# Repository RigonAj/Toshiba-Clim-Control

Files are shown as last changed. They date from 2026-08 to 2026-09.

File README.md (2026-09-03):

# Pilotage infrarouge de climatiseurs Toshiba par ESP32

Deux climatiseurs Toshiba, **aucune fonction connectée**, une seule télécommande. Ce projet leur en
donne une : deux boîtiers autonomes à base d'ESP32-S3 qui rejouent le protocole infrarouge de la
télécommande d'origine, servent leur propre interface Web et tiennent un planning horaire.

**Sans serveur domotique, sans cloud, sans machine allumée en permanence** — chaque boîtier fonctionne
seul, y compris si l'autre est débranché.

<p align="center">
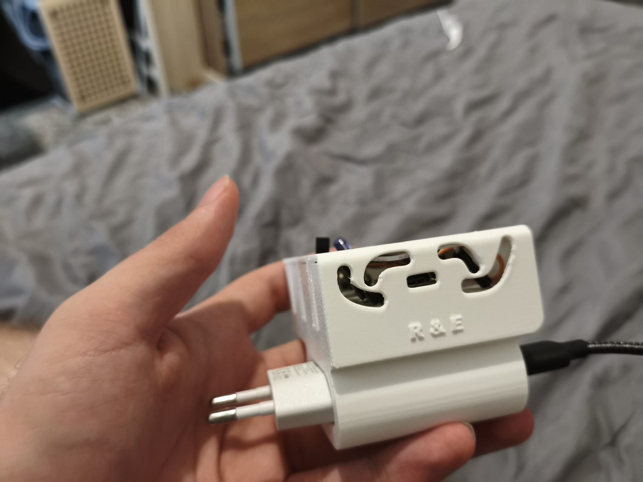
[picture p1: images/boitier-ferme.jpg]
Le boîtier fermé, monté sur son chargeur USB
  
</p>

## Ce que ça fait

- **Rétro-ingénierie du protocole** de la télécommande Toshiba WH-TG01NE, mesuré au récepteur IR
  plutôt que supposé.
- **Émission infrarouge** par un étage transistor + LED IR modulé à 38 kHz.
- **Interface Web servie par la carte elle-même**, en fichiers statiques : la modifier est un
  téléversement, pas une recompilation.
- **Planning horaire** en escalier, avec des points « maintenus » qui neutralisent un rallumage à la
  télécommande.
- **Boîtier conçu et imprimé en 3D**, qui se clipse sur un chargeur USB mural.

## Le résultat principal — le protocole est mesuré

C'est le verrou du projet, et il est levé. La télécommande émet un `TOSHIBA_AC` standard de **72 bits**
(modèle *Remote A*), répété deux fois par appui, porteuse 38 kHz.

```text
octet    0    1    2    3    4    5    6    7    8
        F2   0D   03   FC   01   4 0  00   00   41
                                 │              └── checksum = XOR des 8 premiers octets
                                 └── quartet haut = température − 17
```

Le checksum et l'encodage de la température sont **vérifiés sur tous les états capturés**. Les champs
mode, ventilation et swing restent à identifier : ils demandent la campagne de captures complète.

Preuve de bout en bout : la carte émet une trame que **son propre récepteur redécode octet pour
octet**, douze fois sur douze.

## Où ça en est

| | |
|---|---|
| Protocole de la télécommande | ✅ identifié et vérifié |
| Étage d'émission IR | ✅ monté et validé (boucle locale 12/12) |
| Interface Web | ✅ servie par la carte, testable sans matériel |
| Campagne de captures (mode / ventilation / swing) | 🟡 en cours |
| Preuve sur le climatiseur réel | 🟡 débloquée — exige d'être devant l'unité intérieure |
| Firmware définitif ESP-IDF | ⬜ volontairement pas écrit : le codec serait bâti sur des suppositions |

## Le matériel

| Élément | Choix |
|---|---|
| Carte | **Seeed XIAO ESP32-S3** (8 Mo flash, 8 Mo PSRAM, antenne IPEX) |
| Réception IR | TSOP38238, alimenté depuis un GPIO — 1,5 mA sur 40 mA admissibles |
| Émission IR | LED IR + transistor commuté à 38 kHz |
| Alimentation | chargeur USB mural, sur lequel le boîtier se clipse |

Le boîtier a été **relevé à la main sur une photo du chargeur**, puis dessiné par-dessus — il n'existait
pas de modèle de cette pièce.

| Relevé CAO sur photo | Prototype sur plaque d'essai | Carte perforée |
|---|---|---|
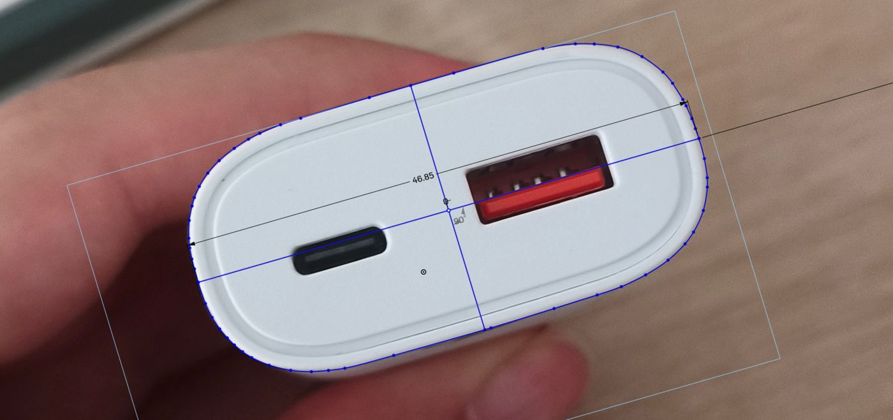
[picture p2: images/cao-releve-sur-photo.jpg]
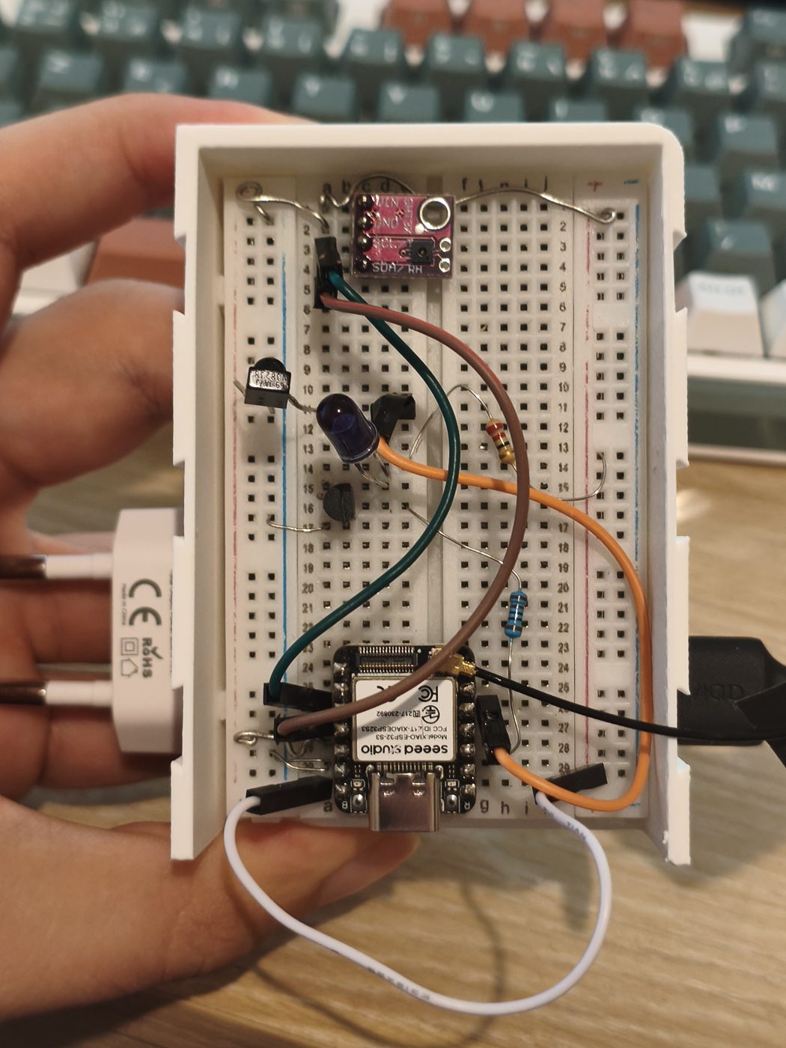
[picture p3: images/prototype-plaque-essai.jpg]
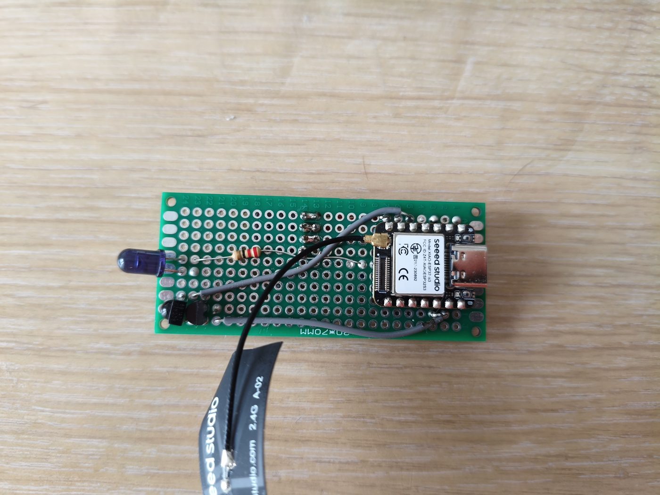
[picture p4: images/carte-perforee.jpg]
|  |  |  |

| Monté sur le chargeur | En place |
|---|---|
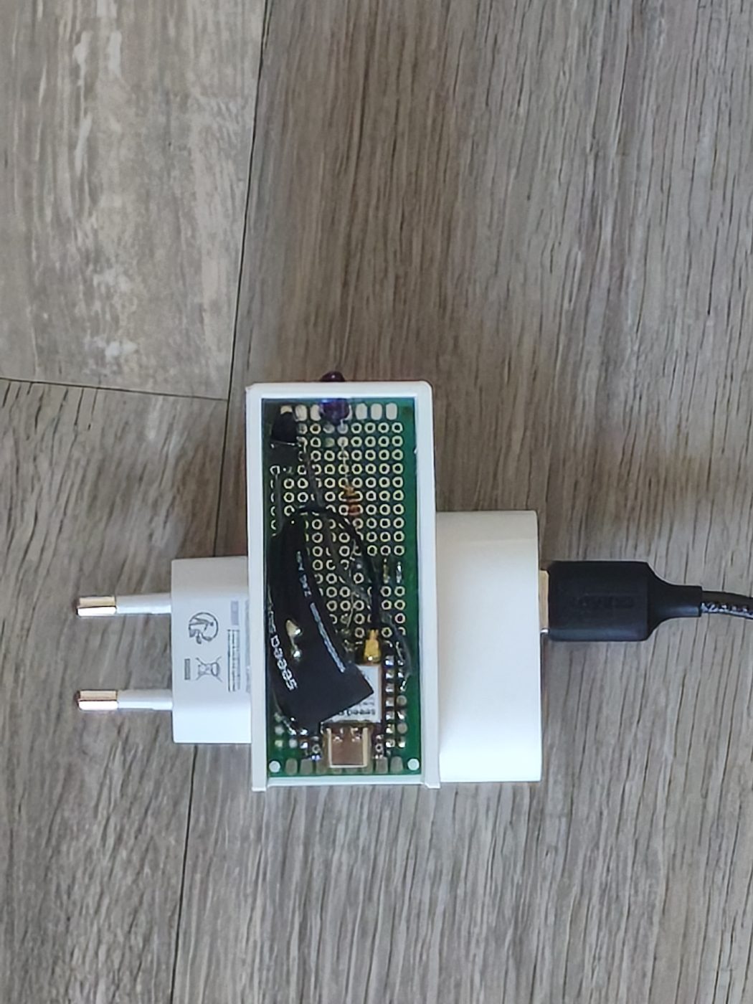
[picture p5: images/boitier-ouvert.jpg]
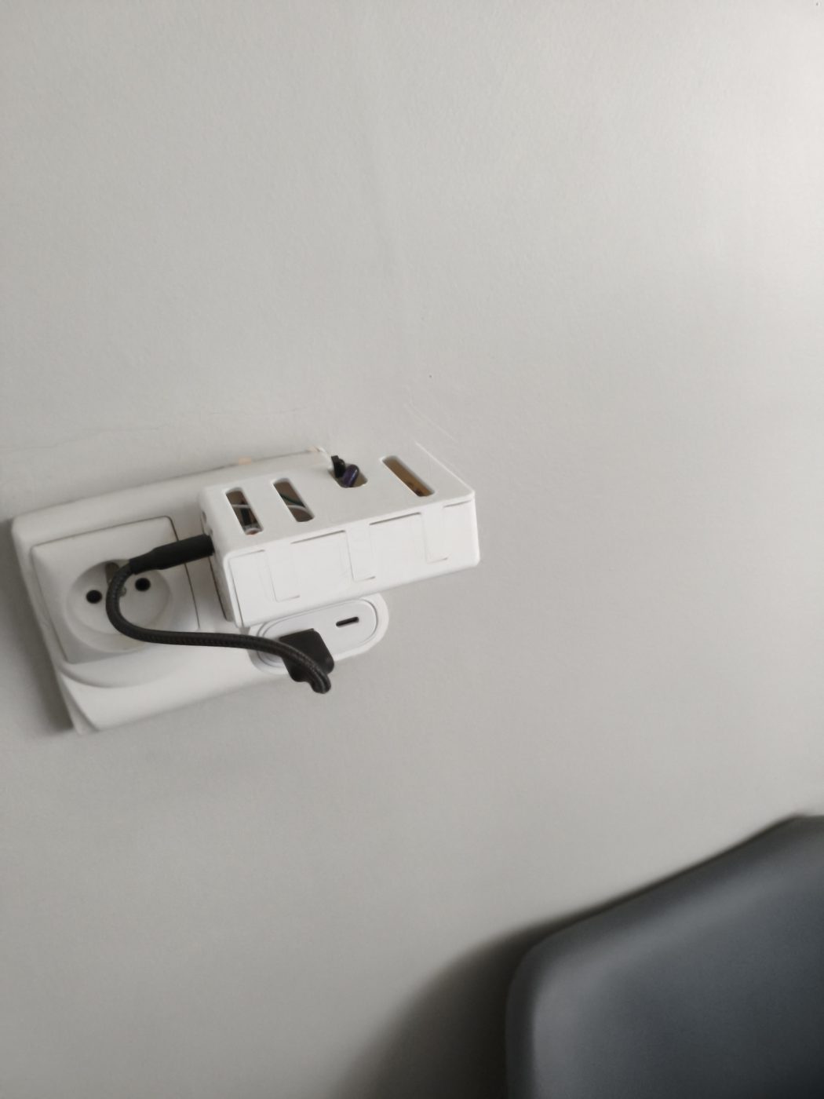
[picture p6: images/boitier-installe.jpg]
|  |  |

Le modèle du boîtier est fourni : [`cad/boitier-clim.step`](cad/boitier-clim.step).

## Contenu du dépôt

```text
ir-capture/                  firmwares de mise au point (PlatformIO) — capture, diagnostic, émission, interface
toshiba-climate-controller/  firmware définitif (à venir) et l'interface Web, en fichiers statiques
captures/                    relevés de la télécommande — des mesures physiques, le contenu le plus précieux
tools/                       export des captures en JSON, et une maquette d'API pour travailler sans matériel
cad/, images/                boîtier imprimé en 3D
docs/                        conception, journal de tests, carnet de mise au point
```

## Essayer sans matériel

L'interface ne dépend ni du codec, ni de la carte. Deux boîtiers simulés, un par terminal :

```bash
python tools/mock_api.py --port 8081 --name Salon --peer "Chambre=http://127.0.0.1:8082"
```

```bash
python tools/mock_api.py --port 8082 --name Chambre --peer "Salon=http://127.0.0.1:8081"
```

Puis ouvrir `http://127.0.0.1:8081/`. Les fichiers de `web/` sont servis tels quels : recharger la page
suffit après modification.

## Avec la carte

```bash
cp ir-capture/include/secrets.example.h ir-capture/include/secrets.h
```

Y mettre le SSID et le mot de passe — **le Wi-Fi doit être en 2,4 GHz**, l'ESP32-S3 ne voit pas le
5 GHz, et l'antenne IPEX doit être branchée avant la mise sous tension. Puis, depuis `ir-capture/` :

```bash
pio run -e webui --target uploadfs && pio run -e webui --target upload && pio device monitor
```

L'adresse IP s'affiche sur la console. Les autres environnements (`capture`, `scan`, `autodetect`,
`txtest`, `carrier`, `loopback`) sont décrits dans le carnet de mise au point.

## Documentation

| Document | Contenu |
|---|---|
| [docs/plan-projet-clim-toshiba-esp32.md](docs/plan-projet-clim-toshiba-esp32.md) | dossier de conception — la référence |
| [docs/cahier-des-charges-v2.md](docs/cahier-des-charges-v2.md) | périmètre étendu : planification et interface |
| [docs/api-v2.md](docs/api-v2.md) | contrat entre l'interface et le firmware |
| [docs/journal-de-tests.md](docs/journal-de-tests.md) | relevés datés, diagnostics, pannes et leur résolution |
| [docs/carnet-mise-au-point.md](docs/carnet-mise-au-point.md) | environnement, outils, câblage, commandes |
| [docs/migration-nouveau-pc.md](docs/migration-nouveau-pc.md) | reprendre le projet sur une autre machine |

## Limites assumées

- Le firmware `webui` n'est **pas** le firmware définitif : ni mot de passe, ni OTA, ni configuration
  persistante. Il ne s'utilise que sur le réseau domestique.
- L'étage d'émission est monté avec des valeurs de substitution : portée d'environ **1,5 m** au lieu
  de 1 à 5 m. Suffisant pour la preuve, pas pour l'installation définitive.
- L'infrarouge ne permet pas d'**empêcher** un démarrage : un point « maintenu » laisse la clim
  s'allumer, puis l'éteint. L'interface l'annonce plutôt que de le masquer.
- Aucune capacité n'est affichée comme acquise tant qu'elle n'est pas mesurée : les champs non
  vérifiés portent une pastille **non vérifié** dans l'interface.

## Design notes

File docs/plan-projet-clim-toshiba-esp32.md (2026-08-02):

---
title: "Projet complet — Pilotage de deux climatiseurs Toshiba par ESP32 et infrarouge"
author: "Dossier de conception"
date: "1er août 2026"
version: "1.1"
lang: "fr"
---

# Projet complet — Pilotage de deux climatiseurs Toshiba par ESP32 et infrarouge

> **Version 1.1 — 1er août 2026**  
> Cible initiale : climatiseur Toshiba `RAS-B18B2KVG-E`, télécommande `WH-TG01NE` portant aussi l'inscription `40525B`.  
> Carte retenue : **Seeed Studio XIAO ESP32-S3**.

### Changements de la version 1.1

La carte cible passe d'un ESP32 DevKit V1 à un **XIAO ESP32-S3** (ESP32-S3R8, 8 Mo de flash, 8 Mo de PSRAM). Ce n'est pas un simple changement de format : le SoC, le brochage disponible, la taille de flash, le périphérique RMT et la liaison série changent tous.

| Point corrigé | Version 1.0 | Version 1.1 |
|---|---|---|
| Brochage IR | GPIO26 / GPIO27 / GPIO25 | D1 (GPIO2) / D2 (GPIO3) / bouton BOOT (GPIO0) |
| Raison | — | Sur ESP32-S3, les GPIO26 à 37 sont réservés à la flash SPI et à la PSRAM octale |
| Flash | 4 Mo, binaire limité à 1,5 Mo | 8 Mo, partitions OTA de 3 Mo, contrainte levée |
| RMT | Blocs de 64 symboles | Blocs de **48** symboles, DMA disponible sur S3 |
| Filtre RX | « ignorer les impulsions < 100 µs » | Impossible au niveau matériel (plafond ~3 µs), filtrage logiciel |
| Console | UART 115200 bauds | USB-Serial-JTAG natif, débit sans objet |
| Étage LED IR | 39 Ω, ≈ 90 mA crête | 22 Ω, ≈ 155 mA crête, pour la portée visée |
| Base du transistor | 330 Ω | 1 kΩ (saturation moins violente) |
| Alternatives | 3 étudiées | Ajout de l'option ESPHome (§17.4) |
| Phase de capture | Firmware de diagnostic à écrire | Chemin rapide `IRremoteESP8266` d'abord (§8.0) |

## Sommaire

1. [Résumé exécutif](#1-résumé-exécutif)
2. [Ce qui est confirmé et ce qui reste à mesurer](#2-ce-qui-est-confirmé-et-ce-qui-reste-à-mesurer)
3. [Objectifs, périmètre et critères de réussite](#3-objectifs-périmètre-et-critères-de-réussite)
4. [Architecture générale](#4-architecture-générale)
5. [Matériel et nomenclature](#5-matériel-et-nomenclature)
6. [Schéma de câblage](#6-schéma-de-câblage)
7. [Architecture du firmware ESP-IDF](#7-architecture-du-firmware-esp-idf)
8. [Identification et validation du protocole IR](#8-identification-et-validation-du-protocole-ir)
9. [Modèle d'état et comportement](#9-modèle-détat-et-comportement)
10. [Interface Web et API](#10-interface-web-et-api)
11. [Réseau, accès WireGuard et sécurité](#11-réseau-accès-wireguard-et-sécurité)
12. [Mises à jour OTA et récupération](#12-mises-à-jour-ota-et-récupération)
13. [Déroulement du projet](#13-déroulement-du-projet)
14. [Plan de tests et recette](#14-plan-de-tests-et-recette)
15. [Risques et mesures de réduction](#15-risques-et-mesures-de-réduction)
16. [Installation, exploitation et maintenance](#16-installation-exploitation-et-maintenance)
17. [Alternatives étudiées](#17-alternatives-étudiées)
18. [Références](#18-références)

---

## 1. Résumé exécutif

Le projet consiste à construire **deux boîtiers autonomes**, un par climatiseur. Chaque boîtier comprend :

- une carte Seeed Studio XIAO ESP32-S3 ;
- un émetteur infrarouge suffisamment puissant pour commander la clim ;
- un récepteur infrarouge 38 kHz qui écoute aussi la télécommande d'origine ;
- une interface Web locale embarquée ;
- un firmware natif ESP-IDF, sans dépendance à un service cloud.

Le premier boîtier, `clim-salon`, servira de **tableau de bord principal**. Il affichera les deux climatiseurs et transmettra les commandes destinées au second boîtier, `clim-chambre`, sur le réseau local. Chaque boîtier restera néanmoins utilisable directement si l'autre est indisponible.

L'accès depuis l'extérieur de la maison passera exclusivement par le serveur **WireGuard déjà actif sur le routeur Asus**. Aucun ESP32 ne sera exposé directement sur Internet et aucune redirection de port ne devra être créée.

Le projet est techniquement faisable, mais il possède un jalon incontournable : **capturer les signaux de la télécommande WH-TG01NE**. Les bibliothèques communautaires savent gérer plusieurs protocoles de climatiseurs Toshiba, mais aucune source publique trouvée ne certifie la combinaison exacte `WH-TG01NE + RAS-B18B2KVG-E`. Le firmware sera donc conçu pour mesurer, décoder, tester puis seulement figer le protocole.

### Résultat attendu

Depuis un téléphone ou un ordinateur connecté au réseau domestique — directement ou par WireGuard — l'utilisateur pourra :

- allumer et éteindre chaque clim ;
- choisir le mode auto, froid, chauffage ou déshumidification ;
- régler la température ;
- choisir la ventilation parmi les valeurs réellement reconnues ;
- activer ou désactiver le swing ;
- voir la disponibilité de chaque boîtier ;
- voir la date et l'origine de la dernière commande connue.

L'interface affichera clairement **« état estimé »**. L'IR est unidirectionnel : même si le récepteur écoute la télécommande d'origine, le système ne peut pas prouver que la clim a reçu ou exécuté une commande.

---

## 2. Ce qui est confirmé et ce qui reste à mesurer

### 2.1 Éléments confirmés

| Élément | Statut | Justification |
|---|---:|---|
| Association `RAS-B18B2KVG-E` / `WH-TG01NE` | Confirmée | Le data book Toshiba de la gamme indique cette télécommande pour l'unité concernée. |
| Commande d'une clim Toshiba par ESP32 et IR | Faisable | Plusieurs implémentations communautaires existent pour des protocoles Toshiba proches. |
| Émission et réception IR natives sur ESP32-S3 | Confirmées | Le périphérique RMT d'Espressif est prévu pour les signaux de télécommande ; l'ESP32-S3 y ajoute la prise en charge du DMA. |
| Accès distant sans cloud | Confirmé | Le routeur Asus fournit déjà un serveur WireGuard actif. |
| Gestion de deux boîtiers sur le LAN | Faisable | Le boîtier principal agrégera l'état du second par API HTTP locale authentifiée. |

### 2.2 Éléments non confirmés avant essais physiques

| Point à vérifier | Pourquoi |
|---|---|
| Timings précis de la `WH-TG01NE` | Les valeurs communautaires servent d'hypothèse, pas de preuve pour cette télécommande. |
| Longueur exacte des trames | Les variantes Toshiba utilisent plusieurs longueurs et parfois plusieurs paquets. |
| Signification de `40525B` | Cette inscription ne doit pas être assimilée à « Remote B » sans capture. |
| Formule du checksum | Elle doit être validée par comparaison de plusieurs commandes. |
| Encodage du mode, du ventilateur et du swing | Les champs peuvent varier entre familles Toshiba. |
| Répétition des paquets | Certaines commandes peuvent comporter un paquet court ou un paquet de swing séparé. |
| Portée réelle de l'émetteur | Elle dépend de la LED, de son courant, de l'angle et de la position du boîtier. |

### 2.3 Décision de passage

Le développement complet de l'interface ne commencera qu'après obtention des trois preuves suivantes :

1. cinq captures cohérentes d'une même commande ;
2. retransmission brute capable de commander réellement la clim ;
3. identification reproductible du préambule, de la longueur et du checksum, ou d'un mécanisme équivalent de validation.

Si le protocole générique Toshiba n'est pas reconnu, le prototype de retransmission brute restera utilisable pour l'analyse, mais il ne sera pas considéré comme la solution finale.

---

## 3. Objectifs, périmètre et critères de réussite

### 3.1 Objectifs fonctionnels de la version 1

- Piloter deux climatiseurs, avec un boîtier par pièce.
- Prototyper et valider complètement le premier avant duplication.
- Disposer d'une page Web unique pour les deux appareils.
- Conserver une page locale de secours sur chaque boîtier.
- Écouter la télécommande d'origine pour maintenir un état estimé plus cohérent.
- Fonctionner sans cloud, abonnement ni compte externe.
- Permettre les mises à jour sans démonter le boîtier.
- Récupérer automatiquement après une coupure de courant ou une mise à jour ratée.

### 3.2 Fonctions incluses

- Marche et arrêt.
- Mode automatique.
- Mode froid.
- Mode chauffage.
- Mode déshumidification.
- Consigne de température, initialement prévue de 17 à 30 °C.
- Ventilation automatique et vitesses découvertes dans les captures.
- Swing activé ou désactivé.
- Diagnostic IR.
- État du réseau et version du firmware.
- Mise à jour OTA locale.

### 3.3 Hors périmètre de la version 1

- Connexion interne CN22/UART.
- Ouverture ou modification électrique de la clim.
- Remplacement de l'adaptateur Wi-Fi officiel Toshiba.
- Retour d'état garanti par la clim.
- Minuterie hebdomadaire.
- Modes silencieux, économie, puissance maximale ou « Hi Power ».
- Capteur de température ambiante indépendant.
- Application mobile native Android/iOS.
- Commande vocale.
- Exposition directe de l'ESP32 à Internet.

### 3.4 Critères de réussite

Le projet est accepté lorsque :

- les deux clims sont commandables depuis la même page ;
- chaque fonction exposée a été validée sur la clim réelle ;
- l'usage de la télécommande d'origine met à jour l'état estimé en moins d'une seconde ;
- les commandes fonctionnent depuis l'emplacement final du boîtier ;
- les deux appareils redémarrent seuls après coupure de courant ;
- l'accès extérieur fonctionne au travers de WireGuard ;
- aucun port des ESP32 n'est publié sur Internet ;
- une mise à jour défaillante provoque un retour automatique au firmware précédent.

---

## 4. Architecture générale

```mermaid
flowchart LR
    TEL["Téléphone / ordinateur"]
    WG["Serveur WireGuard<br/>routeur Asus"]
    LAN["Réseau local"]
    P["ESP32 principal<br/>clim-salon"]
    S["ESP32 secondaire<br/>clim-chambre"]
    AC1["Toshiba salon"]
    AC2["Toshiba chambre"]
    RC1["Télécommande 1"]
    RC2["Télécommande 2"]

    TEL -->|"VPN chiffré"| WG
    TEL -->|"Wi-Fi local"| LAN
    WG --> LAN
    LAN --> P
    P -->|"HTTP local + jeton"| S
    P -->|"IR 38 kHz"| AC1
    S -->|"IR 38 kHz"| AC2
    RC1 -->|"IR écouté"| P
    RC2 -->|"IR écouté"| S
```

### 4.1 Rôle du boîtier principal

`clim-salon` :

- héberge la page générale ;
- expose l'état local ;
- interroge `clim-chambre` toutes les cinq secondes ;
- relaie les commandes destinées au second appareil ;
- signale le second boîtier hors ligne après trois échecs consécutifs ;
- ne bloque jamais sa propre commande IR si le second appareil est indisponible.

### 4.2 Rôle du boîtier secondaire

`clim-chambre` :

- pilote sa clim localement ;
- possède la même interface directe que le principal ;
- accepte les appels du principal avec un jeton d'appairage ;
- reste accessible par son adresse réservée en cas de panne du principal.

### 4.3 Synchronisation

Le principal récupère l'état du secondaire avec `GET /api/v1/status`. Une commande distante est envoyée avec un identifiant unique `command_id`. Le secondaire mémorise les 32 derniers identifiants pendant cinq minutes afin qu'une répétition réseau ne produise pas deux émissions IR.

### 4.4 Alternative : agrégation côté navigateur

Le relais principal/secondaire décrit ci-dessus coûte un composant `peer_client`, un jeton d'appairage, une interrogation périodique et un mode de panne supplémentaire.

Une variante consiste à déployer **deux boîtiers strictement identiques**, sans rôle, et à laisser la page servie par l'un interroger les deux adresses en JavaScript. Les sections `peer_task`, `peer_client` et `GET /api/v1/devices` disparaissent alors.

Contrainte à connaître avant de choisir : les deux boîtiers ayant des adresses IP distinctes, les appels sont considérés comme inter-sites par le navigateur. Un cookie `SameSite=Strict` tel que défini au §11.3 ne serait pas transmis. Cette variante impose donc un jeton porteur conservé côté navigateur et envoyé en en-tête `Authorization`, ainsi que des en-têtes CORS sur l'API.

Le choix entre les deux est à trancher au début de la phase 6, une fois le codec validé. La version 1 conserve par défaut l'architecture principal/secondaire du §4.1, qui n'impose aucune modification du modèle d'authentification.

---

## 5. Matériel et nomenclature

### 5.1 Nomenclature

| Composant | Prototype | Projet final | Spécification / rôle |
|---|---:|---:|---|
| Seeed XIAO ESP32-S3 | 1 | 2 | ESP32-S3R8, 8 Mo flash, 8 Mo PSRAM, USB-C |
| Antenne externe IPEX | 1 | 2 | Fournie avec la carte, **indispensable** ; connecteur fragile |
| Récepteur IR | 1 | 2 | `TSOP38438`, démodulé, 38 kHz, sortie à collecteur ouvert avec tirage interne |
| LED IR | 1 | 2 | `TSAL6400`, 940 nm, demi-angle ±25° |
| Transistor de commande | 1 | 2 | `PN2222A`, ou MOSFET logique `2N7002` / `AO3400` |
| Résistance de base | 1 | 2 | 1 kΩ, 1/4 W — inutile avec un MOSFET |
| Résistance de rappel | 1 | 2 | 10 kΩ, 1/4 W |
| Résistance LED IR | 1 | 2 | 22 Ω, 0,5 W — voir §5.2 |
| Résistance de découplage TSOP | 1 | 2 | 100 Ω, 1/4 W, en série avec l'alimentation du TSOP38438 |
| Condensateur céramique | 1 | 2 | 100 nF près du TSOP38438 |
| Condensateur électrolytique | 1 | 2 | 4,7 µF près du TSOP38438 |
| Condensateur réservoir | 1 | 2 | 100 µF sur le rail 5 V, près de l'étage d'émission |
| Bouton poussoir | 0 | 0 | Non requis : le bouton `BOOT` de la carte est réutilisé |
| Alimentation USB-C | 1 | 2 | 5 V, 1 A minimum, de qualité |
| Câble USB-C | 1 | 2 | Alimentation et maintenance |
| Plaque d'essai | 1 | — | Prototype uniquement |
| Plaque à souder ou PCB | — | 2 | Montage final |
| Boîtier | — | 2 | Ouverture pour LED IR, fenêtre pour le TSOP, accès USB-C, sortie d'antenne |

Prévoir quelques composants de rechange, en particulier deux LED IR, deux récepteurs, deux transistors et **une antenne IPEX supplémentaire** : le connecteur u.FL du XIAO supporte mal les branchements répétés.

Le XIAO ESP32-S3 ne dispose pas d'antenne céramique intégrée : l'antenne externe doit être branchée avant toute mise sous tension avec le Wi-Fi actif.

### 5.2 Justification de l'étage d'émission

Aucune broche du XIAO ne doit alimenter directement la LED IR : le maximum admissible par GPIO sur ESP32-S3 est très inférieur au courant utile. Le transistor fournit le courant d'impulsion, la broche ne fournit que le courant de base.

Avec une alimentation de 5 V, une chute d'environ 1,3 V dans la LED, environ 0,2 V dans le transistor saturé et une résistance de 22 Ω :

```text
Icrête ≈ (5,0 - 1,3 - 0,2) / 22 ≈ 155 mA
```

Ce courant n'est jamais continu. Il est haché par la porteuse à 38 kHz avec un rapport cyclique de 33 %, à l'intérieur de trames qui elles-mêmes ne durent que quelques dizaines de millisecondes et ne sont émises que sur action de l'utilisateur. Le courant moyen réel reste très faible.

La version 1.0 prévoyait 39 Ω, soit environ 90 mA crête : suffisant en visée directe à 2 ou 3 mètres, insuffisant pour la cible de 1 à 5 mètres avec un boîtier posé en biais. La valeur retenue est donc 22 Ω.

Contraintes à respecter :

- vérifier le courant d'impulsion maximal sur la fiche technique de la LED réellement achetée, ainsi que les conditions de durée et de rapport cyclique associées ;
- contrôler la valeur au multimètre, et à l'oscilloscope si disponible ;
- prévoir le condensateur réservoir de 100 µF sur le rail 5 V : les pistes du XIAO sont fines et les appels de courant à 155 mA feraient chuter la tension d'alimentation de la carte.

Le passage de 330 Ω à 1 kΩ pour la résistance de base réduit la sur-saturation du transistor. Avec 330 Ω, le courant de base atteignait environ 8 mA pour 155 mA de collecteur, soit un facteur de sur-commande inutile qui ralentit le blocage. Un MOSFET à seuil logique supprime complètement la question.

### 5.3 Placement

- Distance cible initiale : 1 à 5 mètres.
- La LED IR doit viser le récepteur de l'unité intérieure.
- Le TSOP38438 doit voir la télécommande depuis la zone d'usage normale.
- **Séparer physiquement la LED IR et le TSOP38438** : les orienter dos à dos et intercaler une cloison opaque. Sans cette précaution, le récepteur verra chaque émission du boîtier avec une amplitude énorme, y compris par réflexion sur les parois, et la relira comme une commande de télécommande. Le masquage logiciel de 150 ms du §9.2 est nécessaire mais ne suffit pas seul.
- Éviter le soleil direct, les lampes halogènes et les éclairages qui saturent le récepteur IR.
- Éloigner l'antenne Wi-Fi de toute masse métallique et ne pas la coincer contre le circuit imprimé.
- Installer le boîtier sans ouvrir la clim ni approcher ses conducteurs secteur.

---

## 6. Schéma de câblage

### 6.0 Brochage du XIAO ESP32-S3

La carte n'expose que onze entrées-sorties, nommées `D0` à `D10` sur la sérigraphie. Ces noms ne correspondent pas aux numéros de GPIO utilisés dans le code.

| Sérigraphie | GPIO | Autre fonction | Retenu pour |
|---|---:|---|---|
| `D0` | 1 | ADC1 | libre |
| `D1` | 2 | ADC1 | **émission IR** |
| `D2` | 3 | ADC1 | **réception IR** |
| `D3` | 4 | ADC1 | libre |
| `D4` | 5 | SDA | libre |
| `D5` | 6 | SCL | libre |
| `D6` | 43 | UART0 TX | réservé, à laisser libre |
| `D7` | 44 | UART0 RX | réservé, à laisser libre |
| `D8` | 7 | SCK | libre |
| `D9` | 8 | MISO | libre |
| `D10` | 9 | MOSI | libre |

Ressources internes utilisées sans câblage :

| Élément | GPIO | Remarque |
|---|---:|---|
| Bouton `BOOT` | 0 | Actif à l'état bas, lisible en fonctionnement, remplace le bouton du §6.3 |
| LED utilisateur | 21 | Allumée à l'état **bas**, sert d'indicateur d'état |
| USB natif | 19 / 20 | Console et téléversement, ne jamais réaffecter |

> **Broches interdites.** Sur ESP32-S3, les GPIO 26 à 37 sont câblés à la flash SPI et à la PSRAM octale du module. Le plan initial utilisait GPIO25, GPIO26 et GPIO27 : ces numéros ne sont pas seulement absents du connecteur du XIAO, leur usage ferait planter le module. Toute reprise de la version 1.0 doit être vérifiée sur ce point.

Les entrées-sorties fonctionnent en **3,3 V**. La broche `5V` de la carte est reliée au VBUS de l'USB-C et ne sert qu'à alimenter l'étage d'émission.

### 6.1 Émetteur IR

```text
                    +5 V
                      │
                [22 Ω / 0,5 W]
                      │
              anode  ─┤>|├─  cathode
                    TSAL6400
                      │
                      C
GPIO2 ───[1 kΩ]─── B  PN2222A
                   │  E
                 [10 kΩ]
                   │  │
GND ───────────────┴──┴────────────────
```

Connexions :

1. `D1` (GPIO2) vers la base du PN2222A au travers de 1 kΩ.
2. Résistance de 10 kΩ entre base et masse.
3. Émetteur du PN2222A à la masse.
4. Collecteur vers la cathode de la LED IR.
5. Anode de la LED vers la broche `5V` du XIAO au travers de 22 Ω / 0,5 W.
6. Condensateur de 100 µF entre `5V` et `GND`, au plus près de la résistance de 22 Ω.
7. Masse de l'alimentation et masse du XIAO communes.

La broche `5V` du XIAO est le VBUS de l'USB-C. L'étage d'émission ne passe donc pas par le régulateur 3,3 V de la carte.

### 6.2 Récepteur IR

```text
                        100 Ω
XIAO 3V3 ──────────────[100 Ω]──────────┬───────── VS   (broche 3)
                                        │
                                    ┌───┴───┐
                                 100 nF   4,7 µF
                                    └───┬───┘
XIAO GND ───────────────────────────────┴───────── GND  (broche 2)

XIAO D2 (GPIO3) ────────────────────────────────── OUT  (broche 1)
```

Le TSOP38438 accepte 2,5 à 5,5 V : l'alimenter en 3,3 V donne directement un niveau logique compatible avec l'ESP32-S3, sans adaptation.

La résistance de 100 Ω en série avec l'alimentation, associée au condensateur de 4,7 µF, forme le filtre recommandé par le fabricant. Elle isole le récepteur du bruit généré par l'étage d'émission et par le Wi-Fi.

La sortie du TSOP38438 possède un tirage interne : **aucune résistance de tirage externe n'est nécessaire** sur `D2`. La sortie est au niveau haut au repos et descend à l'état bas en présence d'une porteuse à 38 kHz.

Vérifier le brochage du composant livré : l'ordre des broches dépend de la référence et du boîtier. Sur un TSOP382xx/384xx Vishay vu de **face**, dôme vers soi et pattes vers le bas, l'ordre est `1 = OUT`, `2 = GND`, `3 = VS`. Ne pas se fier uniquement à la forme du boîtier.

### 6.3 Bouton

Le XIAO ESP32-S3 possède un bouton `BOOT` relié à GPIO0, lisible pendant le fonctionnement normal. Il remplace le bouton poussoir externe de la version 1.0 ; aucun câblage n'est requis.

```text
Bouton BOOT intégré ─── GPIO0 ─── actif à l'état bas
```

Le firmware active la résistance de tirage interne :

- appui de 3 secondes : démarrage du mode de configuration Wi-Fi ;
- appui de 8 secondes : effacement de la configuration réseau, de l'administrateur et de l'appairage, puis redémarrage ;
- aucun effacement du firmware ni des journaux de capture exportés.

> **Attention.** GPIO0 est une broche de démarrage. Maintenu enfoncé **au moment du reset ou de la mise sous tension**, le bouton `BOOT` fait entrer la carte en mode téléversement au lieu de lancer le firmware. Les appuis longs décrits ci-dessus ne doivent donc être effectués que carte déjà démarrée. Ce comportement est utile en secours : il garantit un accès au flashage même avec un firmware défaillant.

La LED utilisateur (GPIO21, allumée à l'état bas) indique l'état courant sans matériel supplémentaire : clignotement lent en mode configuration, allumage fixe une fois connecté, flash bref à chaque émission IR.

### 6.4 Contrôles avant alimentation

- Antenne IPEX branchée sur la carte.
- Absence de court-circuit entre `5V` et `GND`, et entre `3V3` et `GND`.
- Aucune tension supérieure à 3,3 V sur une broche `D0` à `D10`.
- Polarité de la LED IR confirmée.
- Brochage du PN2222A confirmé sur sa fiche technique.
- Brochage du TSOP38438 confirmé, dôme vers soi.
- Résistance de 22 Ω présente en série avec la LED.
- Résistance de 100 Ω présente en série avec l'alimentation du TSOP38438.
- Masse commune présente.
- Aucun fil relié à la clim elle-même.

---

## 7. Architecture du firmware ESP-IDF

### 7.1 Version et composants

- ESP-IDF `v5.5.3`, cible `esp32s3`.
- Langages C et C++.
- FreeRTOS pour les tâches concurrentes.
- Pilotes `driver/rmt_tx.h` et `driver/rmt_rx.h`.
- `esp_http_server` pour HTTP et WebSocket.
- `esp_wifi`, `esp_netif` et mDNS.
- NVS pour la configuration.
- `esp_ota_ops` pour les mises à jour et le rollback.
- `esp_timer` pour les délais fins.
- `esp_sntp` pour l'heure UTC.
- cJSON pour les charges utiles JSON.

La version `v5.5.3` est figée dans le projet. Un changement de branche ESP-IDF devra passer par une compilation complète et la recette de non-régression.

Options `sdkconfig.defaults` spécifiques à la carte :

| Option | Valeur | Raison |
|---|---|---|
| `CONFIG_IDF_TARGET` | `esp32s3` | Cible du XIAO |
| `CONFIG_ESPTOOLPY_FLASHSIZE_8MB` | activé | 8 Mo de flash |
| `CONFIG_ESP32S3_SPIRAM_SUPPORT` | activé | 8 Mo de PSRAM octale |
| `CONFIG_SPIRAM_MODE_OCT` | activé | Le module est un ESP32-S3**R8** |
| `CONFIG_ESP_CONSOLE_USB_SERIAL_JTAG` | activé | Console sur l'USB natif |
| `CONFIG_PARTITION_TABLE_CUSTOM` | activé | Table du §7.5 |

La PSRAM n'est pas nécessaire au produit fini, mais elle permet de conserver en mémoire un grand nombre de captures brutes pendant la phase 2.

### 7.1.1 Console série

Le XIAO ESP32-S3 ne comporte **aucune puce USB-UART**. Le connecteur USB-C attaque directement le périphérique USB-Serial-JTAG intégré au SoC. Conséquences :

- la notion de débit en bauds n'a plus d'objet ; la valeur `115200` mentionnée dans le plan initial est ignorée ;
- à chaque redémarrage, `panic` ou téléversement, le périphérique USB **disparaît et réapparaît sur l'hôte**. Le terminal se déconnecte et les messages émis pendant la réénumération sont perdus ;
- ce comportement se produit précisément au moment le plus gênant, c'est-à-dire lors d'un plantage pendant une capture.

Deux mesures compensent ce point :

1. L'export des captures par HTTP en JSON, déjà prévu au §8.1, devient le mécanisme principal et non un complément.
2. En cas de besoin d'une trace vraiment continue, un adaptateur USB-TTL peut être raccordé à `D6` / `D7` (UART0), qui sont laissés libres pour cette raison.

### 7.2 Organisation prévue

```text
toshiba-climate-controller/
├── CMakeLists.txt
├── sdkconfig.defaults
├── partitions.csv
├── main/
│   ├── app_main.c
│   └── CMakeLists.txt
├── components/
│   ├── climate_state/
│   ├── ir_transport/
│   ├── toshiba_codec/
│   ├── ir_diagnostics/
│   ├── settings/
│   ├── wifi_manager/
│   ├── auth/
│   ├── web_api/
│   ├── peer_client/
│   └── ota_manager/
├── web/
│   ├── index.html
│   ├── app.css
│   └── app.js
├── test/
│   ├── test_toshiba_codec/
│   ├── test_climate_state/
│   └── fixtures/
└── tools/
    ├── capture_export/
    └── sign_firmware/
```

### 7.3 Tâches FreeRTOS

| Tâche | Priorité relative | Responsabilité |
|---|---:|---|
| `ir_rx_task` | Haute | Réarmer le RMT RX, normaliser et transmettre les captures au décodeur |
| `ir_tx_task` | Haute | Sérialiser les émissions et gérer la période d'ignorance de l'écho |
| `climate_task` | Normale | Valider les changements et maintenir `ClimateState` |
| `web_task` | Normale | Servir l'interface et l'API |
| `peer_task` | Basse | Interroger le second boîtier toutes les cinq secondes |
| `maintenance_task` | Basse | NVS différée, SNTP, santé et journaux |

Les callbacks RMT exécutés en contexte d'interruption ne feront aucun traitement lourd. Ils déposeront uniquement un événement dans une file FreeRTOS avec les variantes `FromISR`.

### 7.4 RMT

L'API `driver/rmt_tx.h` et `driver/rmt_rx.h` d'ESP-IDF v5 est identique sur ESP32 et ESP32-S3, mais le périphérique sous-jacent diffère. L'ESP32-S3 dispose de **4 canaux d'émission et 4 canaux de réception séparés**, de blocs mémoire de **48 symboles** au lieu de 64, et — contrairement à l'ESP32 d'origine — d'un **accès DMA**.

Configuration initiale :

- résolution : 1 MHz, donc 1 tick = 1 µs ;
- porteuse TX : 38 kHz ;
- rapport cyclique : 33 % ;
- GPIO TX : **2** (`D1`) ;
- GPIO RX : **3** (`D2`) ;
- `mem_block_symbols` : multiple de 48 ;
- `flags.with_dma = true` sur le canal de réception ;
- fin de trame : `signal_range_max_ns` = 20 ms ;
- tampon utilisateur : au moins 512 symboles ;
- tolérance initiale de décodage : ±20 %, plafonnée à ±150 µs pour les impulsions courtes.

#### Correction : filtre de réception

Le plan initial demandait « ignorer les impulsions inférieures à 100 µs » au niveau du périphérique. **Ce réglage n'est pas réalisable en matériel.** Le registre de filtre anti-parasite du RMT est codé sur 8 bits dans le domaine d'horloge du groupe, ce qui plafonne `signal_range_min_ns` aux environs de **3 µs**. Une valeur de `100000` ns fait échouer `rmt_receive()` avec `ESP_ERR_INVALID_ARG`.

La configuration retenue est donc :

- `signal_range_min_ns` réglé à sa valeur utile réelle, de l'ordre de 1 à 2 µs, pour éliminer les parasites électriques ;
- le rejet des impulsions courtes mais non parasites, jusqu'à 100 µs, effectué **en logiciel** dans `ir_rx_task`, après copie des symboles.

Ce filtrage logiciel est de toute façon préférable : il est ajustable sans recompilation du pilote et les durées écartées restent visibles dans les diagnostics du §10.2.

#### Correction : taille des tampons

Avec des blocs de 48 symboles, un canal de réception peut au mieux emprunter la mémoire de ses voisins et atteindre 192 symboles, ce qui est inférieur aux 256 symboles annoncés en version 1.0. Une trame de climatiseur Toshiba, longue et souvent répétée, dépasse cette valeur.

Le pilote sait gérer ce cas par bascule automatique entre demi-blocs, en recopiant au fil de l'eau vers un tampon utilisateur plus grand. Les trames longues passent donc, à condition que le traitement d'interruption suive. L'activation du **DMA**, disponible sur ESP32-S3, supprime entièrement cette contrainte et écarte le risque de capture tronquée. C'est le réglage retenu, d'autant qu'une capture tronquée pendant la phase 2 serait interprétée à tort comme une variante de protocole.

Le seuil de fin de trame de 20 ms reste valide : à une résolution de 1 MHz, `signal_range_max_ns` peut exprimer jusqu'à environ 32,7 ms.

Les timings finaux seront remplacés par les médianes mesurées sur les captures valides.

### 7.5 Partition flash de référence

Le XIAO ESP32-S3 embarque **8 Mo de flash**, et non 4 Mo. La table est donc redimensionnée :

| Partition | Offset | Taille | Rôle |
|---|---:|---:|---|
| `nvs` | `0x9000` | `0x6000` | Configuration et état |
| `otadata` | `0xF000` | `0x2000` | Sélection OTA |
| `phy_init` | `0x11000` | `0x1000` | Initialisation radio |
| `ota_0` | `0x20000` | `0x300000` | Firmware A, 3 Mo |
| `ota_1` | `0x320000` | `0x300000` | Firmware B, 3 Mo |
| `storage` | `0x620000` | `0x1E0000` | Assets, captures et diagnostics, 1,875 Mo |

Fichier `partitions.csv` correspondant :

```text
# Name,   Type, SubType, Offset,   Size
nvs,      data, nvs,     0x9000,   0x6000
otadata,  data, ota,     0xF000,   0x2000
phy_init, data, phy,     0x11000,  0x1000
ota_0,    app,  ota_0,   0x20000,  0x300000
ota_1,    app,  ota_1,   0x320000, 0x300000
storage,  data, spiffs,  0x620000, 0x1E0000
```

La contrainte « binaire inférieur à 1,5 Mo » de la version 1.0 est **supprimée**. Elle était en réalité problématique : ESP-IDF avec Wi-Fi, serveur HTTP, WebSocket, OTA et interface embarquée atteint couramment 1,3 à 1,5 Mo, ce qui laissait une marge quasi nulle et aurait bloqué toute évolution, notamment l'ajout ultérieur du HTTPS local évoqué au §11.3.

Le contrôle de taille à la compilation est conservé, mais avec un seuil d'alerte à 2,5 Mo.

La partition `storage` de 1,875 Mo permet de conserver sur la carte l'intégralité des captures de la phase 2 plutôt qu'uniquement les dix dernières.

---

## 8. Identification et validation du protocole IR

### 8.0 Reconnaissance rapide avant tout développement

Le jalon de décision du §2.3 est le point le plus structurant du projet. Il ne justifie pas d'écrire d'abord un firmware de diagnostic complet.

La première action, une fois le montage de réception câblé, consiste à téléverser sur le XIAO l'exemple `IRrecvDumpV3` de la bibliothèque **IRremoteESP8266**, sous Arduino ou PlatformIO. Cette bibliothèque connaît déjà plusieurs variantes du protocole `TOSHIBA_AC`. En pointant la `WH-TG01NE` vers le TSOP38438, la sortie indique directement :

- si la trame est reconnue comme `TOSHIBA_AC`, et sous quelle longueur ;
- les octets d'état décodés ;
- la validité du checksum interne ;
- à défaut, le tableau brut des durées, directement exploitable pour la matrice du §8.2.

Cette étape demande une trentaine de minutes et tranche l'inconnue principale du projet avant tout investissement. Elle conditionne la suite :

| Résultat | Conséquence |
|---|---|
| Protocole reconnu et checksum valide | La phase 4 se réduit à transcrire un format connu ; l'option ESPHome du §17.4 devient réellement compétitive |
| Trame lue mais non reconnue | Le plan se déroule tel que prévu, avec des captures déjà exploitables |
| Rien n'est capté | Le problème est matériel et non protocolaire ; reprendre le §6.2 avant toute autre chose |

Vérifier que la version d'`IRremoteESP8266` utilisée prend en charge l'ESP32-S3 : ce support est arrivé tardivement dans la bibliothèque.

Le firmware de diagnostic du §8.1 reste nécessaire pour la campagne complète et pour l'export versionné, mais il est écrit **après** cette reconnaissance, avec la connaissance du format réel.

### 8.1 Firmware de diagnostic

Après l'étape §8.0, un firmware ESP-IDF spécialisé sera compilé avec :

- réception RMT continue sur GPIO3, DMA activé ;
- journalisation sur la console USB-Serial-JTAG, sans notion de débit ;
- export JSON des durées, mécanisme principal de récupération compte tenu des coupures USB décrites au §7.1.1 ;
- tentative de décodage Toshiba ;
- retransmission brute d'une capture sélectionnée ;
- page locale de diagnostic permettant de télécharger les dix dernières captures.

Format d'une capture :

```json
{
  "schema_version": 1,
  "device": "WH-TG01NE",
  "label": "cool_22_auto_swing_off",
  "sample": 1,
  "captured_at": "2026-07-25T12:00:00Z",
  "carrier_hz_assumed": 38000,
  "durations_us": [4380, 4370, 540, 1620, 540, 540],
  "decoded_bytes": [],
  "checksum_valid": false
}
```

Les exemples de durée ci-dessus sont seulement illustratifs. Les valeurs du produit seront celles réellement mesurées.

### 8.2 Matrice de capture

Pour chaque ligne, effectuer cinq pressions espacées d'au moins deux secondes :

| Identifiant | Commande |
|---|---|
| `off` | Arrêt |
| `cool_17_auto_off` | Froid, 17 °C, ventilation auto, swing arrêté |
| `cool_22_auto_off` | Froid, 22 °C, ventilation auto, swing arrêté |
| `cool_30_auto_off` | Froid, 30 °C, ventilation auto, swing arrêté |
| `heat_17_auto_off` | Chauffage, 17 °C |
| `heat_22_auto_off` | Chauffage, 22 °C |
| `heat_30_auto_off` | Chauffage, 30 °C |
| `auto_22_auto_off` | Auto, 22 °C |
| `dry_22_auto_off` | Déshumidification, 22 °C |
| `cool_22_fan_N_off` | Une capture par vitesse de ventilation |
| `cool_22_auto_on` | Swing activé |
| `cool_22_auto_off_2` | Swing désactivé après activation |

Les piles de la télécommande doivent être neuves ou vérifiées. La télécommande sera placée à 20–50 cm du récepteur pendant l'analyse.

### 8.3 Méthode d'analyse

1. Supprimer les captures tronquées ou saturées.
2. Aligner les cinq captures d'une même commande.
3. Regrouper les durées en marques, espaces courts, espaces longs et séparateurs.
4. Calculer la médiane et l'écart maximal par groupe.
5. Déterminer l'ordre des bits, la longueur et les éventuels paquets multiples.
6. Rechercher le préambule Toshiba communautaire, notamment `F2 0D`, sans le considérer comme obligatoire.
7. Comparer deux commandes ne différant que par un paramètre.
8. Identifier les octets de température, mode, ventilateur et swing.
9. Dériver puis vérifier le checksum sur toutes les captures.
10. Créer un vecteur de test « trame brute ↔ état » pour chaque commande.

Une trame n'est acceptée que si la longueur, le préambule ou marqueur équivalent, les champs de cohérence et le checksum sont valides.

### 8.4 Stratégie de repli

Si le format n'est pas reconnu :

- conserver les captures brutes ;
- prouver la portée par retransmission brute de `off` et `cool_22_auto_off` ;
- capturer des paires qui ne diffèrent que d'un seul paramètre ;
- documenter les bits variables ;
- implémenter le codec seulement lorsque le checksum est compris.

La retransmission brute ne sera pas étendue à toutes les combinaisons. Une matrice brute complète serait difficile à maintenir et risquerait de masquer une erreur de protocole.

### 8.5 Encodeur et décodeur

Le composant `toshiba_codec` fournira :

```c
esp_err_t toshiba_encode(
    const climate_state_t *state,
    toshiba_frame_t *frame);

esp_err_t toshiba_decode(
    const rmt_symbol_word_t *symbols,
    size_t symbol_count,
    climate_state_t *state,
    toshiba_decode_info_t *info);
```

`toshiba_decode_info_t` contiendra au minimum :

- longueur détectée ;
- timings moyens ;
- octets bruts ;
- validité du checksum ;
- variante de protocole ;
- motif du rejet.

---

## 9. Modèle d'état et comportement

### 9.1 Type principal

```c
typedef enum {
    CLIMATE_MODE_AUTO,
    CLIMATE_MODE_COOL,
    CLIMATE_MODE_HEAT,
    CLIMATE_MODE_DRY
} climate_mode_t;

typedef enum {
    CLIMATE_SOURCE_WEB,
    CLIMATE_SOURCE_REMOTE,
    CLIMATE_SOURCE_RESTORED
} climate_source_t;

typedef enum {
    CLIMATE_CONFIDENCE_FRESH,
    CLIMATE_CONFIDENCE_STALE,
    CLIMATE_CONFIDENCE_UNKNOWN
} climate_confidence_t;

typedef struct {
    bool power;
    climate_mode_t mode;
    uint8_t target_temperature_c;
    uint8_t fan;
    bool swing;
    climate_source_t source;
    climate_confidence_t confidence;
    int64_t updated_at_unix;
    uint32_t revision;
} climate_state_t;
```

### 9.2 Règles

- Température acceptée : 17 à 30 °C, sauf si les captures prouvent une plage différente.
- Les valeurs de ventilation sont découvertes puis inscrites dans la configuration de capacité.
- Un changement Web valide produit une trame complète et incrémente `revision`.
- Une trame reçue de la télécommande met à jour l'état uniquement après validation complète.
- Pendant une émission, le RX est masqué ; il reste ignoré 150 ms après la fin.
- L'état est `fresh` pendant quinze minutes après une commande ou une capture valide.
- Après quinze minutes, il devient `stale`.
- Après le premier démarrage sans état restauré, il est `unknown`.
- Un état restauré depuis NVS est immédiatement `stale`.
- L'état n'est écrit en NVS qu'après deux secondes sans modification afin de limiter l'usure de la flash.

### 9.3 Échec d'émission

Le succès RMT signifie seulement que le signal a été émis. L'API répond :

- `transmitted: true` si la transaction RMT s'est terminée ;
- `confirmed_by_ac: false` dans tous les cas de la version IR ;
- `state.confidence: fresh` pour signaler une estimation récente, pas une confirmation.

---

## 10. Interface Web et API

### 10.1 Interface utilisateur

La page sera embarquée dans le firmware et ne chargera aucune ressource externe.

Elle comportera :

- une barre d'état avec connexion, heure et version ;
- deux cartes, `Salon` et `Chambre` ;
- un bouton marche/arrêt ;
- un sélecteur de mode ;
- des boutons `–` et `+` pour la température ;
- un sélecteur de ventilation ;
- un interrupteur de swing ;
- la mention visible `État estimé` ;
- l'heure et la source de la dernière modification ;
- un indicateur `En ligne`, `Hors ligne` ou `État inconnu` ;
- une zone d'administration séparée pour Wi-Fi, pairage, diagnostic et OTA.

Les contrôles du second appareil sont désactivés s'il est hors ligne. L'appareil local reste commandable.

### 10.2 API

Toutes les réponses utilisent UTF-8 et `application/json`.

#### `GET /api/v1/status`

Réponse :

```json
{
  "schema_version": 1,
  "device_id": "clim-salon",
  "display_name": "Salon",
  "role": "primary",
  "online": true,
  "state": {
    "power": true,
    "mode": "cool",
    "target_temperature_c": 22,
    "fan": "auto",
    "swing": false,
    "source": "web",
    "confidence": "fresh",
    "updated_at": "2026-07-25T12:00:00Z",
    "revision": 42
  },
  "capabilities": {
    "temperature_min_c": 17,
    "temperature_max_c": 30,
    "modes": ["auto", "cool", "heat", "dry"],
    "fans": ["auto", "low", "medium", "high"],
    "swing": true
  },
  "wifi": {
    "rssi_dbm": -54,
    "ip": "192.168.1.40"
  },
  "firmware": "1.0.0"
}
```

#### `PUT /api/v1/climate`

Requête :

```json
{
  "command_id": "01J3R5H9V8K3W6Y2P0B4M7Q9X1",
  "power": true,
  "mode": "cool",
  "target_temperature_c": 22,
  "fan": "auto",
  "swing": false,
  "expected_revision": 41
}
```

Réponse :

```json
{
  "accepted": true,
  "transmitted": true,
  "confirmed_by_ac": false,
  "state": {
    "power": true,
    "mode": "cool",
    "target_temperature_c": 22,
    "fan": "auto",
    "swing": false,
    "source": "web",
    "confidence": "fresh",
    "revision": 42
  }
}
```

`expected_revision` évite d'écraser silencieusement une modification plus récente. Une révision différente produit `409 Conflict` avec l'état courant.

#### `GET /api/v1/devices`

Disponible sur le principal. Retourne les deux objets de statut et l'heure du dernier contact avec le secondaire.

#### `GET /api/v1/diagnostics/ir`

Réservé à l'administrateur. Retourne :

- les dix dernières captures ;
- la dernière trame décodée ;
- les timings mesurés ;
- le checksum ;
- les compteurs de trames valides et rejetées.

#### `POST /api/v1/system/ota`

Accepte une image `.bin` et sa signature. La taille maximale est vérifiée avant écriture.

#### `GET /healthz`

Réponse minimale :

```json
{
  "status": "ok",
  "uptime_s": 86400,
  "ir_rx": true,
  "ir_tx": true,
  "nvs": true
}
```

#### `/ws`

WebSocket authentifié. Événements :

- `state.changed` ;
- `device.online` ;
- `device.offline` ;
- `ir.received` ;
- `ota.progress` ;
- `error`.

### 10.3 Codes d'erreur

| Code | Usage |
|---:|---|
| 400 | JSON ou valeur invalide |
| 401 | Session ou jeton absent/invalide |
| 403 | Action interdite ou CSRF invalide |
| 404 | Ressource inconnue |
| 409 | Révision d'état obsolète ou OTA déjà active |
| 413 | Firmware ou charge utile trop grande |
| 429 | Trop de tentatives de connexion |
| 503 | File IR pleine ou second appareil inaccessible |

---

## 11. Réseau, accès WireGuard et sécurité

### 11.1 Mise en service Wi-Fi

Au premier démarrage :

1. L'ESP32 génère un mot de passe d'installation aléatoire de douze caractères.
2. Il l'affiche sur le port série.
3. Il crée `Clim-Toshiba-Setup-XXXX`.
4. L'utilisateur se connecte à ce point d'accès.
5. Une page locale demande le SSID, le mot de passe Wi-Fi, le nom du boîtier, son rôle et le mot de passe administrateur.
6. Les données sont enregistrées dans NVS.
7. Le point d'accès disparaît après connexion réussie.

La configuration ne réapparaît qu'après un appui de trois secondes sur le bouton `BOOT` (GPIO0), carte déjà démarrée, ou si la connexion échoue pendant cinq minutes consécutives.

Le mot de passe d'installation étant affiché sur la console USB, tenir compte du §7.1.1 : ouvrir le terminal **avant** la mise sous tension, sinon le message est manqué. Le mot de passe est réaffiché toutes les dix secondes tant que le point d'accès est actif.

### 11.2 Paramétrage du routeur Asus

- Créer une réservation DHCP pour chaque adresse MAC.
- Nommer les réservations `clim-salon` et `clim-chambre`.
- Autoriser les clients WireGuard à joindre le sous-réseau domestique.
- Vérifier que le profil téléphone inclut la route du LAN.
- Ne créer aucune règle NAT ou redirection TCP vers les ESP32.
- Si l'isolation des clients Wi-Fi est active, autoriser explicitement les communications entre les deux ESP32.

Les adresses IP réservées seront saisies dans la configuration du principal. mDNS pourra être activé pour le confort local, mais le fonctionnement ne dépendra pas de sa traversée dans WireGuard.

### 11.3 Authentification

- Mot de passe administrateur : minimum douze caractères.
- Stockage : PBKDF2-HMAC-SHA-256, sel aléatoire de 128 bits, 100 000 itérations.
- Session : jeton aléatoire de 256 bits.
- Cookie : `HttpOnly`, `SameSite=Strict`.
- Durée : trente minutes d'inactivité, douze heures maximum.
- Protection CSRF sur toutes les modifications.
- Limitation : cinq échecs de connexion par minute, puis attente progressive.
- Appairage entre boîtiers : jeton aléatoire de 256 bits distinct du compte administrateur.

Le trafic HTTP local n'est pas exposé sur Internet. WireGuard chiffre le trajet extérieur ; le Wi-Fi domestique doit rester protégé par WPA2 ou WPA3. L'activation d'un serveur HTTPS local avec autorité privée pourra être ajoutée plus tard si le réseau local n'est pas considéré comme fiable.

### 11.4 Journalisation

Les journaux ne contiennent jamais :

- mot de passe Wi-Fi ;
- mot de passe administrateur ;
- jeton de session ;
- jeton d'appairage ;
- clé WireGuard.

Ils peuvent contenir :

- identifiant de commande tronqué ;
- résultat d'émission ;
- code d'erreur ;
- timings IR ;
- version du firmware ;
- RSSI et adresse IP locale.

---

## 12. Mises à jour OTA et récupération

### 12.1 Format

Chaque version produit :

- `toshiba-climate-controller.bin` ;
- `toshiba-climate-controller.bin.sig` ;
- un manifeste JSON avec version, taille et SHA-256.

La signature ECDSA P-256 est créée hors de l'ESP32. Seule la clé publique est intégrée au firmware.

### 12.2 Déroulement

1. L'administrateur sélectionne le binaire et sa signature.
2. Le firmware vérifie la taille et la signature.
3. Il écrit dans la partition OTA inactive.
4. Il redémarre sur cette partition.
5. Le nouveau firmware initialise NVS, RMT, Wi-Fi et serveur Web.
6. Il se déclare valide seulement après réussite de ces contrôles, dans les trente secondes.
7. En cas de crash ou d'échec, le bootloader revient à la version précédente.

### 12.3 Récupération

- L'USB reste accessible sans démonter entièrement le boîtier.
- Le bouton de maintenance ne détruit jamais les deux partitions OTA.
- Une image de secours et les commandes de flashage sont conservées avec la documentation.
- La configuration NVS possède un numéro de schéma et des migrations explicites.

---

## 13. Déroulement du projet

### Phase 0 — Documentation et préparation

Livrables :

- dossier de conception ;
- nomenclature ;
- câblage ;
- liste des captures ;
- critères de recette ;
- répertoire de sauvegarde des captures.

Sortie de phase : composants disponibles et montage revu.

### Phase 1 — Prototype électrique

L'ordre est important : le **récepteur seul d'abord**, sans l'étage d'émission. Il n'y a rien à valider côté émission tant qu'on ne sait pas ce qu'il faut émettre, et un émetteur monté trop tôt pollue les captures.

Actions, étape 1a — réception seule :

- brancher l'antenne IPEX ;
- monter le TSOP38438 selon le §6.2 sur une plaque d'essai ;
- vérifier la présence du 3,3 V et le brochage avant mise sous tension ;
- confirmer que la sortie `OUT` est au niveau haut au repos et bascule à l'appui d'une touche de la télécommande ;
- exécuter la reconnaissance rapide du §8.0.

Actions, étape 1b — émission, seulement après captures exploitables :

- monter l'étage transistorisé du §6.1 ;
- contrôler le courant impulsionnel de la LED ;
- tester le bouton `BOOT` ;
- vérifier que le TSOP38438 ne relit pas les émissions du boîtier, cloison en place.

Sortie de phase : aucune surchauffe et captures RMT stables.

### Phase 2 — Capture de la WH-TG01NE

Actions :

- exécuter la reconnaissance `IRremoteESP8266` du §8.0 et décider de la suite ;
- exécuter la matrice complète ;
- sauvegarder cinq échantillons par commande ;
- documenter l'état visible sur l'écran de la télécommande ;
- éliminer les captures incohérentes.

Sortie de phase : jeu de captures versionné et reproductible.

### Phase 3 — Preuve sur la clim

Actions :

- retransmettre `off` ;
- retransmettre `cool_22_auto_off` ;
- tester à 1 m, 3 m puis à l'emplacement final ;
- ajuster l'orientation, pas le courant au-delà des limites du composant.

Sortie de phase : la clim réagit aux deux commandes.

### Phase 4 — Codec Toshiba

Actions :

- dériver le format ;
- implémenter encodeur et décodeur ;
- intégrer le checksum ;
- créer les tests unitaires à partir des captures ;
- valider tous les états exposés.

Sortie de phase : toutes les captures de référence passent les tests.

### Phase 5 — Produit local

Actions :

- ajouter NVS, Wi-Fi, authentification et interface Web ;
- ajouter l'écoute permanente de la télécommande ;
- gérer redémarrage et état obsolète ;
- ajouter diagnostics.

Sortie de phase : une clim est pilotable de façon autonome.

### Phase 6 — Multi-appareils et WireGuard

Actions :

- installer le second firmware ;
- réserver les adresses DHCP ;
- créer le jeton d'appairage ;
- activer l'agrégation ;
- tester depuis le réseau mobile au travers de WireGuard.

Sortie de phase : les deux clims sont utilisables depuis la même page.

### Phase 7 — OTA, boîtiers et recette

Actions :

- activer signature et rollback ;
- souder les montages ;
- installer les boîtiers ;
- exécuter la recette ;
- sauvegarder binaires, signatures, configuration non secrète et captures.

Sortie de phase : projet version 1 accepté.

### Charge indicative

| Phase | Charge indicative hors attente de matériel |
|---|---:|
| Prototype et mesure | 0,5 à 1 jour |
| Capture et analyse | 1 à 2 jours |
| Codec et tests | 1 à 4 jours selon variante |
| Web, état et sécurité | 2 à 4 jours |
| Multi-appareils et WireGuard | 0,5 à 1 jour |
| OTA, boîtiers et recette | 1 à 2 jours |

Le principal facteur d'incertitude est le protocole exact de la WH-TG01NE.

---

## 14. Plan de tests et recette

### 14.1 Tests unitaires

- Encodage de chaque fixture vers les octets attendus.
- Décodage de chaque capture vers l'état attendu.
- Rejet d'un checksum modifié.
- Rejet d'une trame tronquée.
- Tolérance aux variations de timing admises.
- Rejet des durées hors tolérance.
- Validation des températures 17 et 30 °C.
- Rejet de 16 et 31 °C.
- Sérialisation et migration du modèle NVS.
- Détection de conflit par `revision`.
- Détection d'un `command_id` déjà traité.

### 14.2 Tests matériels

- Vérifier la porteuse à 38 kHz.
- Mesurer le courant d'impulsion de la LED IR et le comparer à la valeur calculée d'environ 155 mA.
- Vérifier que la tension sur la broche `5V` ne s'effondre pas pendant une trame, condensateur de 100 µF en place.
- Vérifier l'absence d'échauffement anormal pendant une heure.
- Mesurer le RSSI antenne branchée puis débranchée, pour confirmer que l'antenne est bien connectée.
- Capturer cinq fois la même commande sans erreur.
- Émettre vingt commandes depuis l'emplacement final.
- Tester avec éclairage normal, pièce sombre et lumière du jour.
- Vérifier que l'émetteur ne crée pas une fausse mise à jour RX.

### 14.3 Tests fonctionnels

Pour chaque clim :

- marche puis arrêt ;
- auto ;
- froid à 17, 22 et 30 °C ;
- chauffage à 17, 22 et 30 °C ;
- déshumidification ;
- chaque ventilation exposée ;
- swing activé et désactivé ;
- commande par télécommande d'origine ;
- redémarrage après commande ;
- restauration de l'état en `stale`.

### 14.4 Tests réseau

- Perte et retour du Wi-Fi.
- Changement d'adresse empêché par la réservation DHCP.
- Second boîtier hors tension.
- Principal hors tension avec accès direct au secondaire.
- Latence et répétition réseau sans double émission.
- Accès par WireGuard depuis un téléphone en 4G/5G.
- Vérification externe de l'absence de redirection de port.
- Rejet d'un jeton pair invalide.
- Expiration de session.
- Protection CSRF.

### 14.5 Tests OTA

- Installation d'une version valide.
- Rejet d'une signature incorrecte.
- Rejet d'un fichier trop grand.
- Coupure simulée pendant le transfert.
- Firmware de test ne validant pas son démarrage.
- Retour automatique à la version précédente.
- Conservation de la configuration après mise à jour.

### 14.6 Fiche de recette finale

| Critère | Seuil | Résultat |
|---|---:|---|
| Captures identiques | 5/5 par commande | À compléter |
| Commandes réussies au point d'installation | 20/20 | À compléter |
| Mise à jour depuis télécommande | < 1 s | À compléter |
| Reconnexion Wi-Fi | < 60 s | À compléter |
| Détection du secondaire hors ligne | < 20 s | À compléter |
| Accès par WireGuard | Fonctionnel | À compléter |
| OTA valide | Réussie | À compléter |
| Rollback | Réussi | À compléter |
| Température des composants | Sans échauffement anormal | À compléter |

---

## 15. Risques et mesures de réduction

| Risque | Probabilité | Impact | Réduction |
|---|---:|---:|---|
| Protocole différent du Toshiba générique | Moyenne | Élevé | Jalon de capture, retransmission brute, analyse différentielle |
| Checksum non compris | Moyenne | Élevé | Captures par paires, nombreux états, comparaison communautaire |
| Portée IR insuffisante | Moyenne | Moyen | Étage transistorisé, LED adaptée, essais à la position finale |
| Récepteur saturé par la lumière | Moyenne | Moyen | Positionnement, découplage, protection mécanique |
| État Web différent de la clim | Élevée | Moyen | Mention « estimé », écoute de la télécommande, date et confiance |
| Double commande réseau | Faible | Moyen | `command_id` idempotent et file d'émission unique |
| Second boîtier indisponible | Moyenne | Faible | Interface locale de secours et dégradation indépendante |
| Perte de configuration | Faible | Moyen | NVS versionnée, écriture différée, sauvegarde |
| Mise à jour défaillante | Faible | Élevé | Deux partitions OTA, signature et rollback |
| Exposition Internet accidentelle | Faible | Élevé | WireGuard uniquement, aucune redirection, vérification de recette |
| Surchauffe de la LED ou du transistor | Faible | Élevé | Résistance dimensionnée, mesure du courant, test d'une heure |
| Brochage erroné d'un composant | Moyenne | Moyen | Vérification systématique des fiches techniques avant alimentation |
| Reprise d'un GPIO de la version 1.0 sur ESP32-S3 | Moyenne | Élevé | Tableau de brochage §6.0, GPIO 26 à 37 interdits, relecture avant chaque câblage |
| Capture RMT tronquée prise pour une variante de protocole | Moyenne | Élevé | DMA activé, contrôle de la longueur, rejet des captures incohérentes |
| Journaux perdus lors d'une coupure USB | Élevée | Faible | Export HTTP prioritaire, UART0 de secours sur `D6`/`D7` |
| Antenne IPEX débranchée ou connecteur cassé | Moyenne | Moyen | Contrôle du RSSI en recette, antenne de rechange en stock |
| Émission relue par le récepteur du même boîtier | Élevée | Moyen | Séparation physique, cloison opaque, masquage RX de 150 ms |

---

## 16. Installation, exploitation et maintenance

### 16.1 Installation

1. Fixer le boîtier sans percer ni ouvrir la clim.
2. Orienter la LED IR vers la fenêtre réceptrice de l'unité.
3. Orienter le récepteur vers la zone d'utilisation de la télécommande.
4. Brancher l'alimentation 5 V.
5. Vérifier l'adresse attribuée par le routeur.
6. Effectuer une commande d'arrêt puis une commande de froid.
7. Marquer physiquement le nom et l'adresse du boîtier.

### 16.2 Utilisation quotidienne

- Vérifier la mention `En ligne`.
- Considérer l'état comme une estimation.
- En cas de doute, envoyer un état complet plutôt qu'une variation relative.
- Utiliser la télécommande normalement dans le champ du récepteur.
- Se connecter d'abord à WireGuard depuis l'extérieur.

### 16.3 Sauvegardes

Conserver hors de l'ESP32 :

- code source et version ESP-IDF ;
- captures IR JSON ;
- fixtures de tests ;
- binaires et signatures des deux dernières versions ;
- schéma de câblage ;
- paramètres non secrets ;
- procédure de récupération USB.

Ne jamais placer les mots de passe ou clés WireGuard dans le dépôt du projet.

### 16.4 Maintenance

- Contrôle trimestriel de l'alimentation et du boîtier.
- Test d'une commande locale et d'une commande WireGuard.
- Mise à jour corrective seulement après recette sur le prototype.
- Conservation d'une version stable connue dans la partition de secours.
- Nouvelle campagne de captures si une télécommande ou une clim différente est ajoutée.

---

## 17. Alternatives étudiées

### 17.1 Adaptateur Wi-Fi Toshiba

La documentation Toshiba mentionne des adaptateurs Wi-Fi officiels pour cette génération. Cette voie est simple matériellement, mais repose sur l'application et l'infrastructure cloud du fabricant. Aucune API locale publique et stable n'a été trouvée pour ce modèle.

### 17.2 Connexion interne UART/CN22

Des projets communautaires comme `esphome_toshiba_suzumi`, `shorai-esp32` et `TConnect` se connectent au bus interne de certaines unités Toshiba. Ils peuvent fournir un retour d'état réel, ce que l'IR ne permet pas.

Cette solution n'est pas retenue pour la version 1 parce que :

- la compatibilité du `RAS-B18B2KVG-E` n'est pas confirmée ;
- elle nécessite l'ouverture de l'unité intérieure ;
- elle expose à des erreurs de niveau logique et à la proximité du secteur ;
- le besoin initial peut être satisfait sans modification de la clim.

### 17.3 ESPHome et Home Assistant

ESPHome propose une plateforme `climate_ir` avec un composant Toshiba, et s'exécute sans difficulté sur un XIAO ESP32-S3. Associé à Home Assistant, il fournit sans développement l'essentiel de ce que décrivent les sections 7, 10, 11 et 12 de ce document : interface utilisateur, agrégation des deux appareils, authentification, mises à jour à distance avec retour arrière, et accès extérieur.

Cette alternative aurait dû figurer dans la version 1.0 : c'est celle qui concurrence le plus directement l'approche retenue.

| Critère | Firmware ESP-IDF dédié | ESPHome + Home Assistant |
|---|---|---|
| Charge de travail | 5 à 14 jours | Un après-midi si le protocole est reconnu |
| Dépendance | Aucune | Une instance Home Assistant à héberger et maintenir |
| Protocole atypique | Contrôle total sur le décodage | Nécessite d'écrire un composant externe |
| Accès distant | WireGuard, déjà prévu | WireGuard également |
| Interface | À écrire entièrement | Fournie |
| Valeur d'apprentissage | Élevée | Faible |

Le choix dépend du résultat du §8.0 et de l'objectif réel :

- si la `WH-TG01NE` est reconnue directement et que le besoin est de piloter les clims rapidement, ESPHome est le choix rationnel ;
- si le protocole s'avère atypique, l'avantage d'ESPHome s'effondre : il faudrait de toute façon écrire le décodage, sans le contrôle qu'offre ESP-IDF ;
- si l'objectif inclut la maîtrise d'ESP-IDF et l'absence de toute infrastructure tierce, le plan principal reste pertinent quel que soit le résultat de la capture.

Cette décision est à prendre à la fin de la phase 2, pas avant.

### 17.4 Cloud tiers

Une passerelle cloud simplifierait parfois l'accès à distance, mais introduirait une dépendance externe, des comptes et une surface de sécurité supplémentaire. WireGuard fournit déjà l'accès nécessaire.

---

## 18. Références

### Documentation officielle

- [Toshiba — Data book Seiya Classic, incluant RAS-B18B2KVG-E et WH-TG01NE](https://www.toshibapro.fi/en/tuotteet/kotitaloudet/split-system/seiya-classic/databook-seiya-classic-e/at_download/file)
- [Espressif — Remote Control Transceiver (RMT)](https://docs.espressif.com/projects/esp-idf/en/latest/esp32/api-reference/peripherals/rmt.html)
- [Espressif — versions publiées d'ESP-IDF](https://github.com/espressif/esp-idf/releases)
- [Toshiba — Home AC Control](https://www.toshiba-aircon.co.uk/wp-content/uploads/2021/09/20210901_OM_1120490404_Toshiba_Home_AC_Control_EN.pdf)

### Références communautaires IR

- [IRremoteESP8266](https://github.com/crankyoldgit/IRremoteESP8266)
- [Protocoles supportés par IRremoteESP8266](https://github.com/crankyoldgit/IRremoteESP8266/blob/master/SupportedProtocols.md)
- [ESPHome — Climate IR, plateforme Toshiba](https://esphome.io/components/climate/climate_ir/)
- [k3a/toshiba-ac](https://github.com/k3a/toshiba-ac)

### Alternatives UART étudiées

- [pedobry/esphome_toshiba_suzumi](https://github.com/pedobry/esphome_toshiba_suzumi)
- [toremick/shorai-esp32](https://github.com/toremick/shorai-esp32)
- [Vpowgh/TConnect](https://github.com/Vpowgh/TConnect)
- [b1scuitdev/Toshiba-ESP32C6-Bridge](https://github.com/b1scuitdev/Toshiba-ESP32C6-Bridge)

---

## Conclusion

Le projet est **réalisable avec un risque technique maîtrisable**. L'électronique, le réseau et l'interface Web utilisent des composants et mécanismes éprouvés. L'unique inconnue structurante est le format exact émis par la `WH-TG01NE`.

La bonne stratégie est donc :

1. construire un émetteur-récepteur IR propre ;
2. mesurer la télécommande ;
3. prouver la retransmission sur la clim ;
4. valider le codec ;
5. seulement ensuite finaliser l'interface et dupliquer le boîtier.

Cette progression évite de construire toute l'application sur une compatibilité supposée et fournit, à chaque étape, un résultat vérifiable.

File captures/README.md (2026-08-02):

# Captures de la télécommande WH-TG01NE

Ce dossier contient des **mesures physiques**. C'est le contenu le plus précieux du projet : le code se réécrit, les captures ne se reproduisent qu'avec la télécommande, la carte et le montage sous la main. Elles servent ensuite de vecteurs de test du codec (plan §14.1).

À versionner et à sauvegarder systématiquement.

## Organisation

```text
captures/
├── README.md
└── raw/
    ├── cool_22_auto_off-1.json
    ├── cool_22_auto_off-2.json
    └── ...
```

Un fichier par pression de touche. **Cinq échantillons par commande**, espacés d'au moins deux secondes (plan §8.2).

## Convention de nommage

`<identifiant>-<numéro d'échantillon>.json`, où l'identifiant vient de la matrice du plan §8.2 :

| Identifiant | Commande |
|---|---|
| `off` | Arrêt |
| `cool_17_auto_off` | Froid, 17 °C, ventilation auto, swing arrêté |
| `cool_22_auto_off` | Froid, 22 °C, ventilation auto, swing arrêté |
| `cool_30_auto_off` | Froid, 30 °C, ventilation auto, swing arrêté |
| `heat_17_auto_off` | Chauffage, 17 °C |
| `heat_22_auto_off` | Chauffage, 22 °C |
| `heat_30_auto_off` | Chauffage, 30 °C |
| `auto_22_auto_off` | Auto, 22 °C |
| `dry_22_auto_off` | Déshumidification, 22 °C |
| `cool_22_fan_N_off` | Une capture par vitesse de ventilation |
| `cool_22_auto_on` | Swing activé |
| `cool_22_auto_off_2` | Swing désactivé après activation |

## Format d'un fichier

Format défini au plan §8.1 :

```json
{
  "schema_version": 1,
  "device": "WH-TG01NE",
  "label": "cool_22_auto_off",
  "sample": 1,
  "captured_at": "2026-08-01T14:32:00Z",
  "carrier_hz_assumed": 38000,
  "durations_us": [4380, 4370, 540, 1620, 540, 540],
  "decoded_bytes": [],
  "checksum_valid": false
}
```

Le tableau `durations_us` se remplit avec la sortie `uint16_t rawData[]` affichée par `ir-capture` sur la console.

## Conditions de mesure

- Piles de la télécommande neuves ou vérifiées.
- Télécommande à **20–50 cm** du TSOP38438.
- Pas de soleil direct ni d'halogène dans le champ du récepteur.
- **L'étage d'émission ne doit pas être monté** pendant cette phase : il pollue les captures (plan, phase 1a).
- Noter dans `label` l'état réellement affiché sur l'écran de la télécommande, pas celui qu'on croit avoir envoyé.

## Tri

Écarter et ne pas versionner :

- les captures marquées `ATTENTION : depassement de tampon` ;
- les captures dont la longueur diffère nettement des quatre autres échantillons de la même commande.

Une capture tronquée prise pour une variante de protocole est un risque identifié au plan §15.

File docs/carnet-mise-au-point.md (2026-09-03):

# Carnet de mise au point — environnement, outils, câblage et commandes

Ce document contient tout ce qui était auparavant dans le `README.md` et qui n'y avait pas sa place :
les chemins de la machine de développement, l'emplacement des chaînes d'outils, les six firmwares de
diagnostic, le câblage provisoire, les commandes de compilation et le détail du protocole.

C'est un **carnet de travail**, pas une présentation. Il vaut pour la machine décrite ; sur une autre,
lire d'abord [migration-nouveau-pc.md](migration-nouveau-pc.md).

Références de conception :
[plan-projet-clim-toshiba-esp32.md](plan-projet-clim-toshiba-esp32.md) (les « §x.y » ci-dessous le
désignent), [cahier-des-charges-v2.md](cahier-des-charges-v2.md),
[api-v2.md](api-v2.md), [journal-de-tests.md](journal-de-tests.md).

---

## 1. Les deux chemins vers le même dossier

Ce projet est accessible par **deux chemins qui désignent physiquement le même dossier** :

| Chemin | Usage |
|---|---|
| `C:\Users\rigon\Documents\Esp Controle clim` | Chemin réel. C'est ce que montre l'explorateur Windows. |
| `C:\esp-clim` | Jonction NTFS créée vers le précédent. **C'est par là qu'il faut compiler.** |

**Pourquoi.** ESP-IDF ne supporte pas les espaces dans les chemins de projet ; la compilation échoue
avec des erreurs difficiles à interpréter. Le chemin réel contient deux espaces. La jonction fournit un
chemin propre sans rien déplacer : les deux vues sont le même dossier, un fichier créé d'un côté
apparaît instantanément de l'autre.

Si la jonction est supprimée par erreur, elle se recrée avec :

```bash
cmd /c mklink /J C:\esp-clim "C:\Users\rigon\Documents\Esp Controle clim"
```

---

## 2. Arborescence du projet

```text
C:\esp-clim\
├── README.md                       ← la présentation du projet
├── .gitignore
│
├── ir-capture/                     PlatformIO — outils de mise au point
│   ├── platformio.ini              sept environnements, voir §4
│   ├── include/
│   │   ├── secrets.example.h       modèle versionné, ne contient rien
│   │   └── secrets.h               [local] SSID et mot de passe — jamais versionné
│   ├── src/
│   │   ├── main.cpp                capture et décodage IR          (env: capture)
│   │   ├── pin_scan.cpp            scan des onze broches           (env: scan)
│   │   ├── autodetect.cpp          auto-détection du récepteur     (env: autodetect)
│   │   ├── tx_blink.cpp            commutation du transistor       (env: txtest)
│   │   ├── tx_carrier.cpp          diagnostic de la porteuse       (env: carrier)
│   │   ├── tx_loopback.cpp         boucle émission → réception     (env: loopback)
│   │   └── webui.cpp               interface Web sur la carte      (env: webui)
│   └── .pio/                       [généré] toolchain et binaires
│
├── captures/                       mesures de la télécommande (plan §8.2)
│   ├── README.md                   convention de nommage et format JSON
│   └── raw/                        relevés validés, checksum vérifié
│
├── toshiba-climate-controller/     firmware définitif — seule l'interface existe (§5)
│   └── web/                        fichiers servis depuis la partition `storage`
│       ├── index.html
│       ├── app.css
│       ├── app.js
│       └── config.example.json     adresses des boîtiers, à copier en `config.json`
│
├── tools/
│   ├── capture_export.py           journal de console → JSON, vérifie le checksum
│   └── mock_api.py                 maquette d'un boîtier : sert `web/` et l'API, sans matériel
│
└── docs/
    ├── plan-projet-clim-toshiba-esp32.md   dossier de conception — la référence
    ├── journal-de-tests.md                 relevés datés, diagnostics, jalons
    ├── cahier-des-charges-v2.md            périmètre étendu : planification et interface
    ├── api-v2.md                           contrat entre l'interface et le firmware
    └── migration-nouveau-pc.md             reprendre le projet sur une autre machine
```

Le firmware définitif n'existe pas encore — voir §5.

### Ce qui est versionné et ce qui ne l'est pas

| Dossier | Versionné | Raison |
|---|:---:|---|
| `ir-capture/src/`, `tools/`, `docs/` | oui | C'est le code et les notes |
| `ir-capture/.pio/` | **non** | ~40 Mo d'artefacts de compilation, entièrement reconstructibles. La chaîne d'outils elle-même, ~1 Go, est ailleurs : dans `~\.platformio` (§3). |
| `captures/` | **oui** | Ce sont des **mesures physiques**, impossibles à reproduire sans le matériel. C'est le contenu le plus précieux du projet. |
| Mots de passe, clés WireGuard, jetons | **jamais** | Plan §16.3 |

---

## 3. Où sont les outils (hors du projet)

Les chaînes de compilation ne sont **pas** dans le dossier projet. Elles sont partagées entre tous les
projets ESP32 de la machine.

| Outil | Emplacement | Rôle |
|---|---|---|
| ESP-IDF v5.4 et v6.0.1 | `C:\esp\v5.4\esp-idf`, `C:\esp\v6.0.1\esp-idf` | Déjà installées sur cette machine. **Le plan §7.1 fige v5.5.3** — à trancher avant d'écrire le firmware définitif |
| Outils ESP-IDF | `C:\Espressif\tools` | Compilateur Xtensa, CMake, Ninja, OpenOCD |
| PlatformIO Core 6.1.19 | `%LOCALAPPDATA%\Programs\Python\Python312\Scripts` | Chaîne Arduino pour les outils de mise au point |
| Python 3.12.10 | `%LOCALAPPDATA%\Programs\Python\Python312` | Socle des deux précédents |

> **Piège de cette machine.** `C:\Espressif\tools\python` (3.11) est fourni par l'installeur ESP-IDF
> et répond à `python` s'il passe devant dans le `PATH`. PlatformIO n'y est **pas** installé, pour ne
> pas polluer l'environnement de l'IDF. Vérifier au besoin :
>
> ```bash
> python -c "import sys; print(sys.executable)"
> ```

**Conséquence pratique :** sauvegarder le dossier projet suffit — et depuis le 1er août 2026 c'est
littéralement vrai, le dossier de conception ayant été rapatrié dans `docs/`. Les outils se
réinstallent, les mesures non. Procédure complète de reprise sur une autre machine :
[docs/migration-nouveau-pc.md](migration-nouveau-pc.md).

---

## 4. Les six firmwares de mise au point

`ir-capture/` regroupe six croquis qui partagent la même carte et la même plaque d'essai. Les trois
premiers travaillent sur la réception, les trois suivants sur l'émission. Ils se sélectionnent par
environnement PlatformIO.

| Environnement | Fichier | Sert à |
|---|---|---|
| `capture` *(défaut)* | `main.cpp` | Décoder les trames de la télécommande et exporter les durées brutes |
| `scan` | `pin_scan.cpp` | Trouver sur quelle broche un signal arrive, quand plus rien ne fonctionne |
| `autodetect` | `autodetect.cpp` | Alimenter le TSOP depuis un GPIO et trouver son orientation tout seul |
| `txtest` | `tx_blink.cpp` | Vérifier que le transistor commute, en continu, sans porteuse |
| `carrier` | `tx_carrier.cpp` | Séparer le continu de la modulation 38 kHz quand la boucle ne reçoit rien |
| `loopback` | `tx_loopback.cpp` | Émettre une trame `TOSHIBA_AC` et la faire redécoder par le TSOP |
| `webui` | `webui.cpp` | Servir l'interface depuis la carte, émettre pour de vrai, et contrôler l'émission au TSOP |

Ces outils sont jetables une fois la phase 3 terminée, **sauf `capture_export.py`** et le contenu de
`captures/`, qui servent de vecteurs de test au codec (plan §14.1).

### L'environnement `webui` — l'interface sur la carte

C'est le seul environnement qui demande une préparation : le Wi-Fi.

1. Copier `include/secrets.example.h` en `include/secrets.h` et y mettre le SSID et le mot de passe.
   Ce fichier est exclu du dépôt par `.gitignore` (plan §16.3) ; le modèle, lui, est versionné parce
   qu'il ne contient rien.
2. Téléverser les fichiers de l'interface — ils sont pris **directement** dans
   `toshiba-climate-controller/web/`, il n'y a jamais deux copies à maintenir.
3. Téléverser le firmware, puis lire l'adresse IP sur la console.

Le Wi-Fi doit être en **2,4 GHz** : l'ESP32-S3 ne voit pas les réseaux 5 GHz. Et le XIAO n'ayant pas
d'antenne intégrée, l'antenne IPEX doit être branchée avant la mise sous tension (plan §5.1).

Ce croquis n'est **pas** le firmware définitif : ni mot de passe, ni OTA, ni NVS versionnée. Il ne
s'utilise que sur le réseau domestique. Ce qu'il apporte, et que la maquette Python ne peut pas
donner : chaque commande de la page émet une vraie trame, que le TSOP de la même carte relit et
compare — le contrôle du plan §14.2, visible dans le panneau *Diagnostic infrarouge* de l'interface.

> **Le contrôle statique de câblage ment.** Le `checkWiring()` de `main.cpp` met la broche en entrée
> avec tirage vers le bas et conclut d'un niveau haut que le TSOP tient la ligne. Il s'est trompé
> dans les deux sens au cours d'une même session : « OK » avec un récepteur muet, « ÉCHEC » avec un
> récepteur parfait. La sortie du TSOP est à collecteur ouvert avec un tirage interne trop faible
> face à celui de l'ESP32. **Le seul indicateur fiable est le comptage de fronts pendant une émission
> connue**, tel que `probeActivity()` l'implémente dans `tx_loopback.cpp`.

### Câblage actuel — provisoire mais validé

Le TSOP est alimenté par une sortie GPIO plutôt que par la broche `3V3`. Il consomme 1,5 mA au
maximum contre 40 mA admissibles par broche : c'est électriquement sain, et ça supprime une source
d'erreur récurrente au montage.

| Patte du TSOP38238 | Broche du XIAO | GPIO |
|---|---|---:|
| `VS` (alimentation) | `D3` — sortie à l'état haut | 4 |
| `GND` (patte du milieu) | `GND` | — |
| `OUT` (signal) | `D4` | 5 |

Le montage définitif reviendra au §6.2 du plan : `VS` → `3V3` au travers de 100 Ω, `OUT` → `D2`.

### Câblage d'émission — monté et **validé**

Faute des composants du §5.1, l'étage du §6.1 est monté avec des substitutions. Chaîne en série
entre le rail 5 V et la masse, la LED IR **anode côté 5 V** :

| Élément | Valeur du plan §6.1 | Valeur montée | Raison |
|---|---|---|---|
| Résistance de collecteur | 22 Ω / 0,5 W | **220 Ω** | seule valeur connue en stock |
| Résistance de base | 1 kΩ | **résistance fixe, 1 kΩ ou 10 kΩ** | valeur non identifiée faute de multimètre ; l'étage fonctionne avec celle en place |
| Rappel de base | 10 kΩ | **absent** | remplacé par une mise à l'état bas dès le `setup()` |
| Réservoir 5 V | 100 µF | **absent** | sans objet au courant réduit |

Le courant tombe de 155 mA à ≈ 15 mA, soit une portée d'environ **1,5 m** au lieu de 1 à 5 m —
assez pour la preuve n° 2 du §2.3, pas pour l'installation définitive.

Le potentiomètre du montage d'origine a été remplacé par une résistance fixe, **1 kΩ ou 10 kΩ, non
identifiée** faute de multimètre. Elle fait l'affaire : l'étage commute jusqu'à 38 kHz avec celle en
place. À trancher si la portée se révélait insuffisante devant la clim — une base sous-attaquée
sature moins bien et coûte du courant de LED.

**L'étage est validé.** Il commute en continu et tient les 38 kHz : la boucle locale émet une trame
`TOSHIBA_AC` de 72 bits que le TSOP redécode sans un octet d'écart, douze fois sur douze.

> La panne du 1er août — « la LED IR reste allumée quel que soit l'état de GPIO2 » — n'était ni un
> transistor claqué ni une erreur de plaque d'essai : **la résistance de base était sur `D2` au lieu
> de `D1`.** `D2` est GPIO3, que `tx_blink.cpp` ne pilote jamais. Récit complet dans
> [docs/journal-de-tests.md](journal-de-tests.md).

---

## 5. Ce qui n'existe pas encore, et pourquoi

Aucun firmware définitif n'est écrit. **C'est volontaire, et la raison a changé.**

Jusqu'au 1er août, la raison était le jalon du §2.3 : ne rien construire avant de connaître le
protocole réel. Ce jalon est maintenant franchi à deux tiers — le protocole est identifié et l'étage
d'émission fonctionne. Il ne manque que la preuve de retransmission sur la clim, qui n'est plus
bloquée par le matériel mais **par le lieu** : elle exige d'être devant l'unité intérieure.

La raison est désormais **la campagne de captures**. L'architecture, elle, est tranchée depuis le
1er août : faute de machine allumée en permanence, la voie ESPHome + Home Assistant est écartée et
le projet part sur un **firmware ESP-IDF autonome**. Instruction complète dans
[docs/cahier-des-charges-v2.md](cahier-des-charges-v2.md).

Deux décisions de conception en découlent et modifient le plan d'origine :

- **Boîtiers symétriques**, sans rôle principal/secondaire (alternative du plan §4.4). Chaque boîtier
  doit exécuter son planning même isolé, ce qui rend le relais du §4.1 inutile.
- **Interface servie en fichiers statiques** depuis la partition `storage`, et non compilée dans le
  firmware. Modifier l'interface devient un téléversement de fichier, sans recompilation ni OTA.

Le firmware sera créé sous `toshiba-climate-controller/`, avec la structure du plan §7.2. Il n'est pas
encore initialisé : la campagne du §8.2 doit d'abord révéler l'encodage des champs mode, ventilation
et swing, faute de quoi le codec serait écrit sur des suppositions.

### L'interface, elle, existe déjà

C'est la conséquence directe de la décision « interface en fichiers statiques » : `web/` ne dépend ni
du codec, ni du réseau, ni de la carte. Elle a donc été écrite pendant que la clim est inaccessible,
et testée contre une maquette d'API — `tools/mock_api.py` — qui joue deux boîtiers sur deux ports.

Ce qui reste à écrire côté firmware pour la brancher est décrit dans
[docs/api-v2.md](api-v2.md) : cinq routes, aucune surprise.

Deux points de conception à connaître avant de la modifier :

- **L'interface ne code en dur aucune capacité.** Les modes et les vitesses de ventilation proposés
  sont ceux que le boîtier déclare dans `capabilities`. Tant que la campagne du §8.2 n'a pas mesuré
  l'encodage de `mode`, `fan` et `swing`, le boîtier les déclare dans `unverified_fields` et
  l'interface affiche la pastille **non vérifié** en face de chacun. Aucune fonction non prouvée
  n'est présentée comme acquise.
- **La courbe de planning est un escalier, pas une interpolation** : un point vaut jusqu'au suivant,
  et le dernier point de la journée déborde sur le début de la suivante.
- **Un point d'arrêt peut être « maintenu »** (`lock`). Pendant ce segment, toute trame vue par le
  TSOP est suivie d'un ordre d'arrêt : c'est ce qui neutralise un rallumage à la télécommande.
  L'infrarouge ne permettant pas d'empêcher la clim de démarrer, elle s'allume puis s'éteint —
  l'interface l'annonce, et le détail est dans [docs/api-v2.md](api-v2.md).

---

## 6. Commandes courantes

> **Le port est `COM4` sur cette machine, plus `COM3`.** `COM3` existe aussi mais désigne un autre
> appareil, un adaptateur CH343. La bonne carte se reconnaît à sa MAC `14:c1:9f:c4:fc:40`, affichée
> au téléversement.

Compiler et flasher le firmware de capture :

```bash
cd C:\esp-clim\ir-capture && pio run -e capture --target upload --upload-port COM4
```

Basculer sur un outil de diagnostic :

```bash
cd C:\esp-clim\ir-capture && pio run -e autodetect --target upload --upload-port COM4
```

Tester la commutation du transistor — observer la LED IR à la caméra d'un téléphone :

```bash
cd C:\esp-clim\ir-capture && pio run -e txtest --target upload --upload-port COM4
```

Vérifier la boucle complète émission → réception :

```bash
cd C:\esp-clim\ir-capture && pio run -e loopback --target upload --upload-port COM4
```

Diagnostiquer la porteuse quand la boucle ne reçoit rien :

```bash
cd C:\esp-clim\ir-capture && pio run -e carrier --target upload --upload-port COM4
```

Lire la console :

```bash
cd C:\esp-clim\ir-capture && pio device monitor --port COM4
```

Exporter un journal de console en captures JSON :

```bash
cd C:\esp-clim && python tools\capture_export.py journal.txt --label cool_22_auto_off
```

Retrouver la carte si le port a changé :

```bash
pio device list
```

Mettre l'interface sur la carte — les fichiers d'abord, le firmware ensuite :

```bash
cd C:\esp-clim\ir-capture && pio run -e webui --target uploadfs --upload-port COM4
```

```bash
cd C:\esp-clim\ir-capture && pio run -e webui --target upload --upload-port COM4
```

Après modification de `web/`, seul le premier est à rejouer : le firmware ne change pas.

Travailler sur l'interface sans matériel — deux boîtiers simulés, un par terminal :

```bash
cd C:\esp-clim && python tools\mock_api.py --port 8081 --name Salon --peer "Chambre=http://127.0.0.1:8082"
```

```bash
cd C:\esp-clim && python tools\mock_api.py --port 8082 --name Chambre --peer "Salon=http://127.0.0.1:8081"
```

Puis ouvrir `http://127.0.0.1:8081/`. Les fichiers de `web/` sont servis tels quels : il suffit de
recharger la page après modification.

Ouvrir un terminal ESP-IDF (pour le firmware définitif, quand il existera) :

```bash
powershell -NoExit -ExecutionPolicy Bypass -File C:\Espressif\tools\Microsoft.v5.4.PowerShell_profile.ps1
```

---

## 7. Matériel et protocole de référence

### Carte

| Élément | Valeur relevée |
|---|---|
| Carte | Seeed XIAO ESP32-S3, SoC ESP32-S3 rev v0.2 |
| Flash | 8 Mo — valide la table de partitions du plan §7.5 |
| PSRAM | 8 Mo embarquée — confirme un ESP32-S3**R8** |
| Adresse MAC | `14:c1:9f:c4:fc:40` — à réserver en DHCP (plan §11.2) |
| Port série | `COM3`, USB-Serial-JTAG natif |
| Récepteur IR | TSOP38**2**38 (AGC2) et non TSOP38438 (AGC4) — fonctionne, voir §4 |

Brochage de référence (plan §6.0) — **les GPIO 26 à 37 sont interdits sur ESP32-S3**, ils sont câblés
à la flash et à la PSRAM :

| Fonction | Sérigraphie | GPIO |
|---|---|---:|
| Émission IR (montée et **validée**) | `D1` | 2 |
| Réception IR (montage définitif) | `D2` | 3 |
| Bouton de maintenance | `BOOT` | 0 |
| LED d'état (allumée à l'état bas) | — | 21 |
| Console USB | — | 19 / 20 |

### Protocole de la WH-TG01NE — mesuré, plus supposé

| Caractéristique | Valeur |
|---|---|
| Protocole | `TOSHIBA_AC`, modèle *Remote A* |
| Longueur | 72 bits — 9 octets |
| Préambule | `F2 0D` |
| Répétition | le paquet est émis **deux fois** par appui, séparation ≈ 5956 µs |
| En-tête | 4396 / 4384 µs |
| Marque | ≈ 546 µs |
| Espace court (0) | ≈ 536 µs |
| Espace long (1) | ≈ 1620 µs |
| Porteuse | 38 kHz |

Encodage connu à ce jour :

```text
octet    0    1    2    3    4    5    6    7    8
        F2   0D   03   FC   01   4 0  00   00   41
                                 │              └── checksum
                                 └── quartet haut = température − 17
```

**Checksum** = OU exclusif des huit premiers octets. Vérifié sur tous les états capturés.

Les champs mode, ventilation et swing restent à identifier : ils demandent la campagne complète de
la matrice du plan §8.2.

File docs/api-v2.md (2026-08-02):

# Contrat d'API — ce que l'interface attend du boîtier

> Rédigé le 1er août 2026, en même temps que l'interface.
> Complète le plan §10.2, qui reste la référence pour tout ce qui n'est pas repris ici.
> L'implémentation de référence — et le moyen de tester l'interface sans matériel — est
> [`tools/mock_api.py`](../tools/mock_api.py).

L'interface est écrite **avant** le firmware. Ce document fige donc l'interface entre les deux :
c'est lui que le composant `web_api` devra satisfaire, et lui qu'il faudra modifier — avant le code —
si un besoin nouveau apparaît.

---

## 1. Principes

| Règle | Raison |
|---|---|
| Tout est en UTF-8, `application/json`, `Cache-Control: no-store` | Plan §10.2 |
| Aucun boîtier n'est « principal » | Cahier v2 §4.1 : boîtiers symétriques, la page interroge les deux |
| En-têtes CORS sur toute l'API | Conséquence directe du point précédent : les appels vers le second boîtier sont inter-origines |
| Authentification par jeton porteur, en-tête `Authorization: Bearer …` | Un cookie `SameSite=Strict` ne serait pas transmis à l'autre boîtier (plan §4.4) |
| Les capacités sont **déclarées par le boîtier**, jamais codées dans la page | L'interface ne doit pas proposer un mode que le codec ne sait pas encore encoder |

Le préflight `OPTIONS` doit répondre `204` avec
`Access-Control-Allow-Headers: Content-Type, Authorization` et
`Access-Control-Allow-Methods: GET, PUT, POST, OPTIONS`.

---

## 2. Fichiers statiques

Servis depuis la partition `storage` (cahier v2 §4.2) :

| Chemin | Rôle |
|---|---|
| `/` → `index.html` | La page |
| `/app.css`, `/app.js` | Ses deux dépendances, aucune autre |
| `/config.json` | **Optionnel.** Adresses des boîtiers livrées avec les fichiers |

`config.json` évite d'avoir à saisir les adresses sur chaque appareil de la maison :

```json
{
  "devices": [
    { "id": "salon",   "name": "Salon",   "base": "" },
    { "id": "chambre", "name": "Chambre", "base": "http://192.168.1.41" }
  ]
}
```

`base` vide désigne le boîtier qui sert la page. Un réglage saisi dans l'interface est mémorisé dans
le `localStorage` du navigateur et **prend le pas** sur `config.json`.

---

## 3. `GET /api/v1/status`

Interrogé toutes les 5 secondes par appareil affiché. Au-delà de 3 secondes sans réponse, le boîtier
est déclaré hors ligne et sa carte est désactivée — les autres restent commandables.

```json
{
  "schema_version": 1,
  "device_id": "clim-salon",
  "display_name": "Salon",
  "online": true,
  "state": {
    "power": true,
    "mode": "cool",
    "target_temperature_c": 22,
    "fan": "auto",
    "swing": false,
    "source": "web",
    "confidence": "fresh",
    "updated_at": "2026-08-01T18:09:09Z",
    "revision": 42
  },
  "capabilities": {
    "temperature_min_c": 17,
    "temperature_max_c": 30,
    "modes": ["auto", "cool", "heat", "dry"],
    "fans": ["auto", "low", "medium", "high"],
    "swing": true,
    "unverified_fields": ["mode", "fan", "swing"]
  },
  "schedule": {
    "enabled": true,
    "active_curve": "week",
    "next_point_at": "22:30",
    "override_active": false,
    "revision": 7
  },
  "time": { "now": "2026-08-01T18:09:09Z", "synced": true },
  "wifi": { "rssi_dbm": -54, "ip": "192.168.1.40" },
  "firmware": "1.0.0"
}
```

### Champs ajoutés au plan §10.2

| Champ | Ce que l'interface en fait |
|---|---|
| `capabilities.unverified_fields` | Affiche la pastille **non vérifié** à côté du réglage concerné. Tant que la campagne du plan §8.2 n'a pas mesuré l'encodage de `mode`, `fan` et `swing`, le boîtier doit les y déclarer : l'interface les propose, mais dit qu'ils ne sont pas prouvés. |
| `schedule.active_curve` | `week` ou `weekend`, calculé par le boîtier. Sert à tracer le repère d'heure courante sur la bonne courbe. |
| `schedule.next_point_at` | Affiché en résumé du panneau *Planning*. |
| `schedule.override_active` | Affiche « réglage manuel en cours » : une commande manuelle tient **jusqu'au point de consigne suivant** (cahier v2 §3). |
| `schedule.lock_active` | Affiche la pastille **maintenu éteint**. Vrai quand le segment en cours porte `lock` et qu'aucun réglage manuel ne le suspend. |
| `time.synced` | À `false`, l'interface affiche « heure non synchronisée ». Aucune action programmée ne doit être exécutée dans cet état, et `state.confidence` vaut `unknown`. |

`role` et `GET /api/v1/devices` du plan §10.2 **disparaissent** : les boîtiers n'ont plus de rôle et
l'agrégation se fait dans le navigateur.

---

## 4. `PUT /api/v1/climate`

Corps envoyé — toujours l'état **complet**, jamais une variation relative (plan §16.2) :

```json
{
  "command_id": "9f2c…",
  "power": true,
  "mode": "cool",
  "target_temperature_c": 22,
  "fan": "auto",
  "swing": false,
  "expected_revision": 41
}
```

Réponse `200` :

```json
{
  "accepted": true,
  "transmitted": true,
  "confirmed_by_ac": false,
  "state": { "…": "état complet, revision incrémentée" }
}
```

- `409` si `expected_revision` ne correspond plus, **avec l'état courant dans `state`** : l'interface
  l'adopte sans discuter et prévient l'utilisateur. C'est ce qui se produit quand la télécommande, le
  planning ou un autre navigateur est passé entre-temps.
- `400` si une valeur sort des capacités déclarées.
- Les appuis rapides sur `+`/`−` sont regroupés côté navigateur : une seule requête part 450 ms après
  le dernier appui. Le boîtier n'a donc pas à amortir la cadence, mais reste tenu de sérialiser ses
  émissions IR (plan §7.3).
- `confirmed_by_ac` vaut toujours `false` en version IR (plan §9.3). L'interface affiche « état
  estimé » en permanence pour cette raison.

---

## 5. Planning — `GET` et `PUT /api/v1/schedule`

Deux courbes seulement, `week` et `weekend` (cahier v2 §3). Points libres sur 24 h, **pas de
30 minutes**.

```json
{
  "schema_version": 1,
  "enabled": true,
  "timezone": "Europe/Paris",
  "revision": 7,
  "curves": {
    "week": [
      { "at": "06:30", "power": true,  "mode": "heat", "temperature_c": 21, "fan": "auto", "swing": false, "lock": false },
      { "at": "08:00", "power": false, "mode": "heat", "temperature_c": 21, "fan": "auto", "swing": false, "lock": true  },
      { "at": "22:30", "power": true,  "mode": "cool", "temperature_c": 26, "fan": "low",  "swing": false, "lock": false }
    ],
    "weekend": []
  }
}
```

Règles de lecture, appliquées à l'identique par l'interface et par l'ordonnanceur :

1. Un point **s'applique jusqu'au point suivant** — la courbe est un escalier, pas une interpolation.
2. Le dernier point de la journée déborde sur le début de la suivante. Une courbe non vide n'a donc
   jamais de trou.
3. Un point avec `power: false` éteint la clim ; ses autres champs sont conservés mais ignorés.
4. Une commande manuelle tient jusqu'au point suivant, puis le planning reprend la main.
5. Une courbe vide ne programme rien. `enabled: false` désactive les deux courbes.
6. `lock` n'a de sens que sur un point d'arrêt (`power: false`) : le boîtier force la valeur à `false`
   sur un point de marche plutôt que de rejeter la requête.

### `lock` — maintien de l'arrêt

Pendant un segment verrouillé, **toute trame reçue du récepteur IR** déclenche, après un délai, le
renvoi d'un ordre d'arrêt.

Le boîtier ne cherche pas à savoir si la télécommande demandait la marche : l'encodage du mode
n'étant pas prouvé (`unverified_fields`), interpréter la trame serait un pari. Réagir à toute trame
est robuste — si elle demandait déjà l'arrêt, le rappel est sans effet.

Contraintes que l'implémentation doit respecter :

| Point | Règle |
|---|---|
| Écho de sa propre émission | Le paquet est émis deux fois : le RX doit être ignoré au moins 1,5 s après chaque émission, sinon le verrou se déclenche sur lui-même, indéfiniment |
| Délai avant rappel | ≈ 2,5 s, le temps que l'unité ait fini de traiter la commande de la télécommande |
| Cadence maximale | Un rappel toutes les 8 s au plus, garde-fou |
| Origine de l'état | `state.source` vaut alors `lock` |
| Suspension | Une commande passée par l'API suspend le verrou jusqu'au point suivant, comme tout réglage manuel. Une trame de la télécommande, jamais. |

**Limite de principe, à énoncer dans l'interface :** l'infrarouge ne permet pas d'empêcher la clim de
recevoir la télécommande. Elle démarre, puis s'arrête. Et le boîtier ne réagit que s'il a *vu* la
trame : une télécommande pointée hors du champ du TSOP passe inaperçue. Un rappel périodique
inconditionnel couvrirait ce cas, au prix d'un bip de l'unité à chaque trame reçue — l'implémentation
de référence le prévoit, désactivé par défaut.

`PUT` accepte `expected_revision`, `enabled` et `curves`, et répond par le planning enregistré, ou
`409` avec le planning courant. Les points sont triés par heure croissante par le boîtier.

> L'heure des points est **locale**, exprimée en `HH:MM`. Le boîtier doit connaître son fuseau et le
> changement d'heure ; sans synchronisation SNTP, il n'exécute rien (`time.synced: false`).

---

## 6. `GET /api/v1/diagnostics/ir`

Réservé à l'administrateur. C'est le panneau qui répond à la question « est-ce que j'émets vraiment
ce que je crois émettre ? », en confrontant la trame émise à ce que le TSOP du même boîtier a relu.

```json
{
  "last_tx": { "at": "…", "bytes": "F2 0D 03 FC 01 50 00 00 51" },
  "last_rx": {
    "at": "…", "bytes": "F2 0D 03 FC 01 50 00 00 51",
    "protocol": "TOSHIBA_AC", "bits": 72,
    "checksum_valid": true, "source": "self"
  },
  "self_check": { "match": true, "checked_at": "…" },
  "counters": { "tx": 12, "rx_valid": 12, "rx_rejected": 0 }
}
```

`source` vaut `self` pour une trame relue de sa propre émission, `remote` pour la télécommande
d'origine. `bytes` est accepté en chaîne hexadécimale ou en tableau d'entiers.

Le plan §10.2 prévoit en plus les dix dernières captures : elles ne sont pas encore utilisées par
l'interface, elles peuvent être ajoutées à cette réponse sans la casser.

---

## 7. `GET /healthz`

Étendu par rapport au plan §10.2, à la suite du diagnostic de lenteur du 2 août : un symptôme réseau
ne se distingue d'un symptôme logiciel que si le boîtier expose de quoi les séparer.

```json
{
  "status": "ok", "uptime_s": 86400, "ir_rx": true, "ir_tx": true, "nvs": true,
  "reset_reason": "mise sous tension",
  "heap": { "free": 276284, "min_free": 269872, "largest_block": 262132 },
  "wifi": { "connected": true, "rssi_dbm": -59, "channel": 1, "bssid": "…",
            "tx_power_dbm": 20, "disconnects": 4, "reconnects": 0,
            "last_disconnect_reason": 201 },
  "ir": { "rx_valid": 12, "rx_rejected": 0, "rx_unknown": 0 },
  "loops_per_s": 24030
}
```

| Champ | Ce qu'il tranche |
|---|---|
| `heap.largest_block` | L'écart avec `free` mesure la fragmentation, qu'un simple « tas libre » masque |
| `loops_per_s` | Processeur accaparé ou non. Quelques milliers = sain, quelques dizaines = quelque chose mange tout |
| `ir.rx_unknown` | Bruit optique : un TSOP ébloui décode en continu sans rien reconnaître |
| `wifi.disconnects` / `last_disconnect_reason` | Liaison instable, avec le code de motif 802.11 |
| `reset_reason` | Distingue un `PANIC`, un watchdog et une chute d'alimentation d'un redémarrage voulu |

### Deux routes de mise au point

- `PUT /api/v1/diagnostics/rx` — corps `{"enabled": false}` : débraye le récepteur infrarouge à
  chaud. Permet de trancher par l'essai si on le soupçonne de peser sur le reste.
- `GET /api/v1/diagnostics/wifi` — fait balayer la bande **par le boîtier** : c'est son point de vue
  qui compte, pas celui du poste de travail. Bloque deux à trois secondes.

### Mise en cache

L'API répond `Cache-Control: no-store`. Les fichiers statiques, eux, portent un `ETag` — empreinte
de l'ensemble des fichiers, calculée au démarrage — et `Cache-Control: no-cache`, qui signifie
« revalider », pas « ne pas garder ». Le navigateur ne retélécharge l'interface que lorsqu'elle a
changé. Sur une liaison mediocre, la différence mesurée est de 14,8 s contre 0,5 s.

---

## 8. Codes d'erreur

Ceux du plan §10.3. Comportement de l'interface :

| Code | Réaction |
|---|---|
| `401` / `403` | Le panneau de diagnostic invite à saisir le jeton ; le reste continue de fonctionner |
| `409` | L'état ou le planning du boîtier est adopté, sans confirmation demandée |
| autre | Message d'erreur temporaire, l'état affiché revient à celui du boîtier |
| pas de réponse en 3 s | Boîtier marqué hors ligne, sa carte est désactivée |

---

## 9. Ce qu'il reste à trancher

- **Comment le jeton est obtenu.** L'interface se contente aujourd'hui de le stocker et de l'envoyer ;
  le plan §11.3 décrit une session par mot de passe, à réconcilier avec le jeton porteur du §4.4.
- **`/ws`** (plan §10.2) : l'interface interroge périodiquement plutôt que d'ouvrir un WebSocket.
  C'est suffisant à 5 secondes et cela supprime une dépendance ; le WebSocket reste utile si l'on veut
  voir la télécommande d'origine agir en moins d'une seconde (critère du plan §3.4).
- **OTA** : `POST /api/v1/system/ota` n'a pas encore d'écran.

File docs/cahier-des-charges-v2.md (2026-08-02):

# Cahier des charges v2 — périmètre étendu

> Rédigé le 1er août 2026, à la suite du franchissement du jalon protocole.
> Complète et modifie le dossier de conception d'origine, sans le remplacer.

---

## 1. Ce qui déclenche cette révision

Deux événements du 1er août 2026 changent les termes du projet.

**Le protocole est identifié.** La `WH-TG01NE` émet un `TOSHIBA_AC` standard de 72 bits, reconnu
directement par les bibliothèques communautaires. Le plan d'origine (§17.3) prévoyait explicitement ce
cas de figure : *« si la WH-TG01NE est reconnue directement et que le besoin est de piloter les clims
rapidement, ESPHome est le choix rationnel »*. Cette branche est donc active.

**Le périmètre s'étend.** La demande porte désormais sur de la planification horaire et une interface
riche, deux points que la version 1 excluait volontairement.

---

## 2. Besoins exprimés

| Réf | Besoin | Statut dans le plan d'origine |
|---|---|---|
| B1 | Consigne de température **variable selon l'heure**, éditée sur un graphe par points déplaçables | Hors périmètre (§3.3, « minuterie hebdomadaire ») |
| B2 | **Marche et arrêt programmés** à des heures données | Hors périmètre (§3.3) |
| B3 | **Toutes les fonctions** de la télécommande : mode, ventilation, swing, température, marche/arrêt | Prévu (§3.2) |
| B4 | Accès à l'interface **depuis tous les appareils de la maison, par navigateur** | Prévu (§10.1) |
| B5 | Deux climatiseurs pilotés depuis la même page | Prévu (§4) |
| B6 | Accès extérieur par le **WireGuard existant**, sans cloud | Prévu (§11) |
| B7 | Solution **facile à concevoir et entretenir par un agent IA** | Nouveau critère, structurant |

Le besoin B7 est le plus important pour l'arbitrage qui suit : il ne porte pas sur ce que le système
fait, mais sur le coût de chaque modification future.

---

## 3. Règles de conception — tranchées le 1er août 2026

| Question | Décision |
|---|---|
| Granularité du planning | **Deux courbes : semaine et week-end** |
| Planning indépendant par pièce, ou commun ? | Indépendant par pièce |
| Modification manuelle pendant un planning actif | **Elle tient jusqu'au point de consigne suivant**, puis le planning reprend la main |
| Heure indisponible au démarrage (pas de réseau) | Aucune action programmée tant que l'heure n'est pas synchronisée. L'état est marqué `unknown`. |
| Résolution du graphe | Pas de 30 minutes, points libres sur 24 h |

La règle de reprise au point suivant est le comportement habituel des thermostats programmables :
elle évite qu'un réglage manuel oublié fige l'installation, tout en respectant une intervention
ponctuelle.

---

## 4. Arbitrage d'architecture

Le protocole étant connu, le choix ne porte plus sur la faisabilité mais sur le coût d'entretien.

### Option A — ESPHome sur les ESP32 + Home Assistant

Les boîtiers deviennent de simples passerelles infrarouges décrites en YAML. Toute l'intelligence —
planification, interface, historique, authentification — est fournie par Home Assistant.

**Ce qui disparaît du plan d'origine :** le composant `peer_client`, le jeton d'appairage,
l'interrogation périodique du boîtier secondaire, le rôle principal/secondaire (§4.1 à §4.3),
l'authentification maison (§11.3), le mécanisme OTA signé (§12), et la totalité de l'API du §10.2.
Home Assistant les fournit tous.

**Reste à écrire :** un tableau de bord, et une carte personnalisée en JavaScript pour le graphe à
points déplaçables — ce composant n'existe pas en standard.

**Exigence :** une machine allumée en permanence pour héberger Home Assistant.

### Option B — Firmware ESP-IDF autonome

Le plan d'origine, augmenté d'un ordonnanceur et d'une interface plus riche. Chaque boîtier est
complètement autonome, aucun serveur tiers.

L'interface serait servie en fichiers statiques depuis la partition `storage` de 1,875 Mo, donc
modifiable sans recompiler le firmware — point important pour le besoin B7.

**Reste à écrire :** tout. Le codec, l'ordonnanceur, l'interface, l'API, l'authentification, l'OTA
signé, la synchronisation entre les deux boîtiers.

### Comparaison au regard du besoin B7

| Critère | A — ESPHome + HA | B — ESP-IDF autonome |
|---|---|---|
| Modifier l'interface | Éditer un fichier, recharger la page — quelques secondes | Éditer des fichiers statiques, les téléverser — une minute |
| Modifier la logique | Éditer du YAML, recharger | Modifier du C, recompiler, OTA sur deux boîtiers, risque de rollback |
| Ajouter une fonction de la télécommande | Un attribut dans le composant `climate` | Encoder le champ, tester, recompiler, redéployer |
| Volume de code à maintenir | ~50 lignes de YAML + une carte JS | ~10 composants C, une API, une interface |
| Historique et courbes de température | Fourni | À écrire |
| Sauvegarde et restauration | Fournie | À écrire |
| Autonomie des boîtiers | Dépend de Home Assistant pour la planification | Totale |
| Dépendance à maintenir | Une instance Home Assistant | Aucune |
| Charge estimée | Un à deux jours | Deux à trois semaines avec le périmètre étendu |

### Recommandation

**L'option A, à condition de disposer d'une machine allumée en permanence.**

Le besoin B7 tranche nettement. Un agent IA entretient bien mieux du texte déclaratif rechargé à chaud
que du C compilé déployé par OTA sur deux appareils : le cycle d'essai passe de quelques minutes à
quelques secondes, et une erreur ne peut pas briquer un boîtier.

S'y ajoute que le périmètre étendu tombe exactement dans ce que Home Assistant fait nativement —
planification, historique, accès multi-appareils, comptes utilisateurs — alors que ce sont précisément
les parties les plus longues à écrire en option B.

Le seul point réellement à construire en option A est la carte du graphe à points déplaçables, et ce
travail serait de toute façon à faire en option B.

**Sans machine allumée en permanence, l'option A est impossible** et l'option B s'impose, avec une
charge nettement supérieure. Un Raspberry Pi d'occasion suffit à basculer dans le cas favorable.

### Décision — 1er août 2026 : option B

Aucune machine n'est allumée en permanence. Le routeur Asus BE88U ne peut pas se substituer à un
hôte : un routeur grand public ne dispose ni de Docker, ni de la mémoire, ni du stockage nécessaires
à Home Assistant, et même contourné par un micrologiciel alternatif, ce serait une base fragile pour
un équipement de confort quotidien.

**Le routeur n'a cependant rien à héberger.** Chaque ESP32 sert lui-même sa page : le routeur se
contente de router, ce qu'il fait déjà. Le besoin B4 est donc satisfait sans lui demander autre chose
que ce que prévoit le plan §11.2 — une réservation DHCP par boîtier, et le WireGuard déjà actif pour
l'accès extérieur.

**L'option B est retenue : firmware ESP-IDF autonome, aucune dépendance à un serveur.**
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

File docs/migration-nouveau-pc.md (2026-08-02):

# Reprendre le projet sur une autre machine

> Rédigé le 1er août 2026, au moment du changement de PC.
> À lire en premier sur la nouvelle machine, avant le [README](../README.md).
>
> **✅ Migration effectuée le 1er août 2026** sur le profil `rigon`. Ce document reste la référence
> pour la *prochaine* machine ; il n'a pas été réécrit après coup. Les écarts constatés à
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

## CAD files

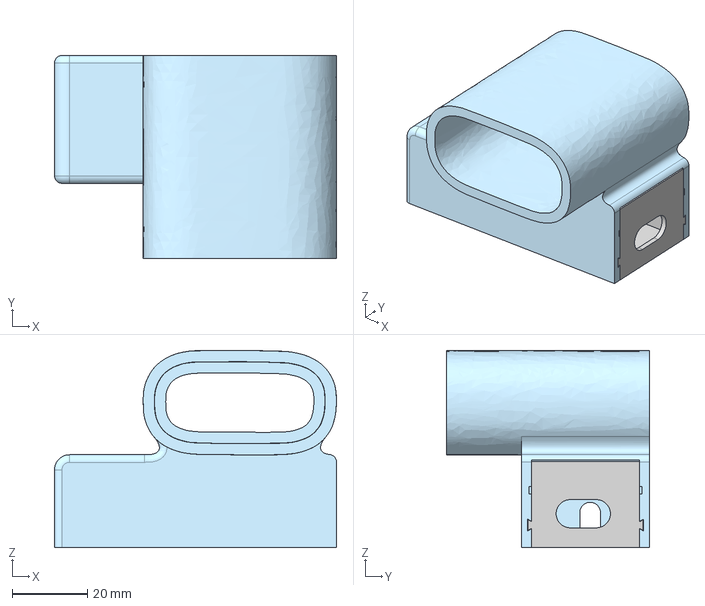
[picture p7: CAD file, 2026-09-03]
cad/boitier-clim.step
75.0 x 54.0 x 52.5 mm

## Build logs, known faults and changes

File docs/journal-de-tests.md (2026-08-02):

# Journal de tests

Relevés datés, dans l'ordre chronologique. Sert de trace pour la fiche de recette du plan §14.6.

---

## 1er août 2026 — Phase 1a, mise en route

### Chaîne d'outils

| Élément | Version | Résultat |
|---|---|---|
| ESP-IDF | v5.5.3 | `hello_world` compilé pour `esp32s3`, 528/528 cibles — **OK** |
| PlatformIO Core | 6.1.19 | croquis Arduino + IRremoteESP8266 compilé pour `seeed_xiao_esp32s3` — **OK** |
| Python | 3.12.10 | — |
| IRremoteESP8266 | 2.9.0 | prend bien en charge l'ESP32-S3 (point de vigilance du plan §8.0) — **OK** |

### Carte

Relevé à l'`esptool` sur `COM3` :

```text
Chip is ESP32-S3 (QFN56) (revision v0.2)
Features: WiFi, BLE, Embedded PSRAM 8MB (AP_3v3)
Crystal is 40MHz
USB mode: USB-Serial/JTAG
MAC: 14:c1:9f:c4:fc:40
Detected flash size: 8MB
```

Conclusions :

- 8 Mo de flash → la table de partitions du plan §7.5 (2 × 3 Mo OTA + 1,875 Mo `storage`) est applicable.
- 8 Mo de PSRAM embarquée → module ESP32-S3**R8**, donc `CONFIG_SPIRAM_MODE_OCT` comme prévu au §7.1.
- USB-Serial-JTAG confirmé → pas de puce USB-UART, le §7.1.1 s'applique (coupures de console au reset).
- MAC `14:c1:9f:c4:fc:40` à réserver en DHCP sur le routeur Asus (§11.2).

### Téléversement

Croquis `ir-capture` flashé sur `COM3` : 446 048 octets écrits, **hash vérifié**, démarrage confirmé.
Le téléversement fonctionne sans manipulation du bouton `BOOT`.

### Test de câblage du récepteur — **ÉCHEC attendu à ce stade**

```text
--- Verification du cablage (plan §1a) ---
GPIO3 au repos : 0 lectures HAUT sur 20
ECHEC : ligne au niveau bas en permanence.
```

Le test met GPIO3 en entrée avec tirage vers le bas et vérifie que le TSOP38438 tient malgré tout la ligne au niveau haut. Vingt lectures basses sur vingt : **rien ne pilote la ligne**.

À vérifier dans cet ordre (plan §6.2 et §6.4) :

1. Le TSOP38438 est-il monté ? Si seule la carte est branchée en USB, ce résultat est normal.
2. Brochage : dôme vers soi, pattes vers le bas → `1 = OUT`, `2 = GND`, `3 = VS`. Un échange VS/GND donne ce résultat.
3. `OUT` (broche 1) relié à `D2`, c'est-à-dire GPIO3 — pas à `D3`.
4. `VS` (broche 3) alimenté depuis `3V3` **au travers de la résistance de 100 Ω**.
5. `GND` commun entre le TSOP et la carte.
6. Condensateurs de découplage 100 nF et 4,7 µF en place près du composant.

Aucune résistance de tirage externe n'est nécessaire : la sortie du TSOP38438 possède un tirage interne.

**Suite :** relancer le test après câblage. Le résultat attendu est `20 lectures HAUT sur 20`, puis basculement à l'appui d'une touche de la télécommande.

### Diagnostic — outil de scan des broches

Le test précédent ne disait pas *si* le TSOP était mal branché ou *où*. Un second croquis a été ajouté
(`ir-capture/src/pin_scan.cpp`, environnement `scan`) : il met les onze entrées-sorties du XIAO en
entrée avec tirage vers le bas et affiche laquelle est tenue au niveau haut.

Premier passage : **les onze broches en l'air**. Le diagnostic bascule alors de « mauvaise broche » vers
« TSOP non alimenté » — déplacer le fil `OUT` n'aurait rien changé.

Fausse piste écartée au passage : l'absence de la résistance de 100 Ω n'est **pas** en cause. Ce n'est pas
une résistance de limitation mais un filtre de découplage (plan §6.2) ; le TSOP38438 fonctionne
sans, alimenté directement en 3,3 V.

Autre point clarifié : la sortie du TSOP est haute **au repos, sans aucun infrarouge**, grâce à son
tirage interne. Un niveau bas permanent signifie donc « pas d'alimentation », jamais « pas de signal ».
Aucune émission IR n'est nécessaire à ce stade — la source, c'est la télécommande.

Incident pendant le recâblage : disparition complète du périphérique USB (VID `303A`), port `COM3`
inclus. Réapparition normale après rebranchement. À surveiller si cela se reproduit — un
court-circuit `3V3`/`GND` produit exactement ce symptôme.

### Test de câblage du récepteur — **SUCCÈS**

Après reprise du câblage :

```text
Broche  GPIO  HAUT/20  Verdict
D2      3     20/20    <<< quelque chose tient cette ligne HAUTE
```

Toutes les autres broches en l'air, comme attendu. Le TSOP38438 est alimenté, sa sortie est tenue au
niveau haut au repos, et elle arrive bien sur `D2` = GPIO3, conforme au plan §6.0.

**Sortie de phase 1a atteinte** pour le volet réception.

**Reste à faire :** la première capture réelle.

### Diagnostic — auto-détection du récepteur

Six scans successifs ont rendu `0/20` sur les onze broches malgré des recâblages répétés. Le montage
dépendait de trois choses invérifiables sans multimètre : la position de la broche `3V3`, l'orientation
du TSOP, et les rangées de la plaque d'essai.

Un troisième croquis (`ir-capture/src/autodetect.cpp`, environnement `autodetect`) supprime les trois
d'un coup : la carte **alimente elle-même le TSOP depuis une sortie GPIO** — le composant consomme
1,5 mA au maximum contre 40 mA admissibles par broche — et essaie les deux affectations possibles
des pattes extérieures.

Deux essais suffisent, et aucun n'inverse l'alimentation : en retournant un boîtier à trois pattes,
les pattes extérieures s'échangent mais celle du milieu reste au milieu, donc la masse est toujours
centrale. Le test est sans risque pour le composant.

```text
--- Essai 1 : alimentation par D3, lecture sur D4 ---
  D4 haute : 20/20
*** RECEPTEUR TROUVE ET FONCTIONNEL ***
  VS  (alimentation) sur D3
  OUT (signal)       sur D4
```

Le TSOP38238 était sain depuis le début. La panne était uniquement dans le câblage d'alimentation.

**Décision :** on conserve l'alimentation par GPIO plutôt que de recâbler vers `3V3`. C'est
électriquement sain et ça supprime une source d'erreur. Le montage définitif reviendra au §6.2.

### Première capture — **PROTOCOLE RECONNU**

Câblage retenu : `VS` ← D3 (GPIO4, sortie à l'état haut), `OUT` → D4 (GPIO5), milieu → `GND`.

```text
Protocole : TOSHIBA_AC
Longueur  : 72 bits (9 octets)
Code      : 0xF20D03FC0140000041
Model: 0 (TOSHIBA REMOTE A), Temp: 21C, Power: On, Mode: Auto, Fan: Auto
```

Quatre trames valides sur cinq. La cinquième, `UNKNOWN` à 148 bits, a été écartée (§8.3, étape 1).

Résultats d'analyse, obtenus par appuis sur les touches température bas puis haut :

| Point du §2.2 | Statut | Valeur mesurée |
|---|---|---|
| Préambule | **Confirmé** | `F2 0D`, exactement l'hypothèse communautaire |
| Longueur de trame | **Mesurée** | 72 bits, 9 octets, paquet émis **deux fois** par appui |
| Signification de `40525B` | **Tranchée** | Remote **A**, et non B comme on aurait pu le supposer |
| Formule du checksum | **Trouvée** | OU exclusif des 8 premiers octets = 9ᵉ octet. Vérifié sur les deux états. |
| Encodage de la température | **Trouvé** | quartet haut de l'octet 5 = température − 17 |

Analyse différentielle (§8.3, étape 7), deux trames ne différant que d'un degré :

```text
21 °C : F2 0D 03 FC 01 40 00 00 41
20 °C : F2 0D 03 FC 01 30 00 00 31
                    ^^       ^^
                    |        checksum recalculé
                    température
```

La plage 17–30 °C retenue au §9.2 est cohérente avec cet encodage : 17 °C donnerait `0x0_`, 30 °C
donnerait `0xD_`.

Timings médians : en-tête 4396 / 4384 µs, marque ≈ 546 µs, espace court ≈ 536 µs, espace long
≈ 1620 µs, séparation entre les deux paquets ≈ 5956 µs.

**Jalon de passage du §2.3 — 2 preuves sur 3 :**

1. Captures cohérentes d'une même commande — trois trames identiques au bit près. Il en faut cinq
   par commande pour la campagne complète du §8.2.
2. Retransmission brute commandant réellement la clim — **non fait**, l'étage d'émission (§6.1)
   n'est pas monté. C'est la phase 1b.
3. Identification reproductible du préambule, de la longueur et du checksum — **fait**.

Outil créé au passage : `tools/capture_export.py`, qui convertit un journal de console en fichiers
JSON au format §8.1 et vérifie le checksum. Réutilisable pour toute la campagne §8.2.

---

## 1er août 2026 — Phase 1b, étage d'émission

### Contrainte de départ : la nomenclature du §5.1 n'est pas disponible

Matériel réellement en main au moment du montage :

| Composant demandé au §5.1 | Disponible | Substitution retenue |
|---|:---:|---|
| LED IR | oui | — |
| Transistor `PN2222A` | oui | — |
| 22 Ω / 0,5 W — collecteur | **non** | 220 Ω, seule résistance de valeur connue |
| 1 kΩ — base | **non** | potentiomètre de kit réglé vers 1 kΩ |
| 10 kΩ — rappel de base | **non** | mise à l'état bas dès la première ligne du `setup()` |
| 100 µF — réservoir 5 V | **non** | sans objet au courant réduit |

Le reste du lot de résistances n'est pas identifié et la machine n'a toujours pas de multimètre.

### Conséquence sur le courant et la portée

Le §5.2 dimensionne l'étage pour 155 mA crête, soit 1 à 5 m. Avec 220 Ω au collecteur :

```text
I ≈ (5,0 − 1,35 − 0,2) / 220 ≈ 15 mA
```

L'éclairement décroît en 1/d², donc la portée varie en √I : `√(15/155) ≈ 0,31`, soit **environ
1,5 m**. Suffisant pour la preuve n° 2 du §2.3, insuffisant pour l'installation définitive.

Solution de repli si le transistor s'avérait inutilisable : attaque directe du GPIO, 3,3 V au
travers de la même 220 Ω, soit ≈ 8 mA et ≈ 1,1 m. Sans risque pour la carte — très loin des
40 mA admissibles par broche — et **de même polarité de commande** que l'étage transistorisé,
donc sans impact sur le firmware.

### Deux montages écartés

**Potentiomètre comme résistance de collecteur.** Écarté sur la puissance, pas sur la valeur : le
calibre d'un potentiomètre s'applique à la piste entière, donc n'utiliser que la fraction *f* de
la piste ne donne droit qu'à *f* × P. Pour 22 Ω sur une piste de 10 kΩ / 0,1 W, cela fait 0,22 %
de piste, soit **0,22 mW admissibles contre 530 mW crête** — plus de 300 fois au-dessus. S'y
ajoutent 0,7° de course utile et une résistance de contact du curseur de 1 à 3 Ω, soit 5 à 15 %
de la valeur visée. En revanche il convient très bien en **résistance de base**, où le courant
n'excède pas 10 mA sous 3,3 V.

**LED visible en guise de résistance.** Écarté sans réserve : une LED est une jonction à tension
de seuil, elle ne limite pas le courant. Une LED rouge (≈ 1,9 V) en série avec la LED IR
(≈ 1,3 V) donnerait 3,2 V de seuil pour 3,3 V d'alimentation, avec un courant dépendant de la
température et de la dispersion de fabrication.

### Outil créé — croquis de clignotement

`ir-capture/src/tx_blink.cpp`, environnement `txtest`. Il n'émet **aucune porteuse 38 kHz** : la
LED est allumée en continu pendant les phases hautes, ce qui la rend franchement observable à la
caméra d'un téléphone. Déroulement : base au niveau bas 5 s, base au niveau haut 5 s, puis
clignotement à 1 Hz. La LED d'état GPIO21 suit la LED IR et fournit une référence visible à
l'œil nu, cadrable dans la même image.

Compilé et téléversé sur `COM3` : 254 625 octets, 7,6 % de la partition, **hash vérifié**.

### Premier essai — **ÉCHEC : le transistor ne commute pas**

```text
Phase 1 : base au niveau BAS  -> LED IR ALLUMEE   (attendu : eteinte)
Phase 2 : base au niveau HAUT -> LED IR ALLUMEE   (attendu : allumee)
```

La LED brille en permanence, indépendamment de l'état de GPIO2. Aucun dommage : 17 mA continus au
travers de 220 Ω, très en dessous des 100 mA que la LED admet en continu.

**Fausse piste écartée d'emblée.** Une inversion base/collecteur n'est pas possible : sur un
`PN2222A` en TO-92 — `E · B · C` — comme sur la quasi-totalité des boîtiers à trois pattes, **la
base est la patte du milieu**. Retourner le composant échange les pattes extérieures et laisse le
milieu au milieu. C'est le raisonnement déjà appliqué au TSOP plus haut. Une inversion E/C, elle,
ferait fonctionner le transistor en mode inverse — gain ≈ 3 au lieu de 100 — et donnerait un
clignotement faible, pas un allumage permanent.

Hypothèses restantes, par ordre de probabilité :

1. **La cathode de la LED n'atteint pas le collecteur** et retombe dans la rangée du `GND`. La LED
   est alors câblée directement entre 5 V et masse, le transistor hors circuit. Une rangée d'écart
   sur la plaque d'essai suffit — jumelle exacte de la panne d'alimentation du TSOP.
2. Le fil du potentiomètre n'est pas sur la patte du milieu, auquel cas la vraie base reçoit la
   branche 5 V et conduit en permanence.
3. Transistor claqué en court-circuit C-E.

**Test discriminant retenu :** débrancher le seul fil émetteur → `GND`, carte alimentée. Si la LED
s'éteint, le transistor est dans le chemin du courant et l'erreur est en 2 ou 3 ; si elle reste
allumée, il n'y est pas du tout et l'erreur est en 1.

**Suite :** diagnostic en cours. La preuve n° 2 du §2.3 reste non acquise.

### Changement de machine — préparation du dossier

Le projet quitte cette machine avant la fin du diagnostic. Trois opérations pour qu'un seul
dossier suffise à tout reprendre :

1. **Dossier de conception rapatrié.** Il vivait hors du projet, dans `Documents\Codex\...`, alors
   que le README §3 affirmait déjà « sauvegarder le dossier projet suffit ». C'était faux : toute
   la documentation cite ce plan à chaque paragraphe. Il est désormais dans
   `docs/plan-projet-clim-toshiba-esp32.md`. Le rendu HTML du 25 juillet n'a **pas** été repris,
   il est antérieur à la révision du 1er août et contredirait la référence.
2. **`ir-capture/.pio/` supprimé** — 39 Mo d'artefacts contenant des chemins absolus figés vers
   l'ancien profil utilisateur. Recopiés, ils cassent la compilation de façon peu lisible.
3. **Procédure de reprise écrite** dans [migration-nouveau-pc.md](migration-nouveau-pc.md) :
   installation, jonction NTFS, port série, inventaire du matériel à emporter, et le geste précis
   par lequel reprendre le diagnostic.

Le dossier fait **206 Ko** pour 20 fichiers. Erreur corrigée au passage dans le README §2 : les
« ~1 Go » attribués à `.pio` désignaient en réalité la chaîne d'outils de `~\.platformio`, qui
n'a jamais été dans le projet.

---

## 1er août 2026 — Nouvelle machine, phase 1b **terminée**

Reprise du projet sur le PC de destination, profil `rigon`. La procédure de
[migration-nouveau-pc.md](migration-nouveau-pc.md) a été suivie sans surprise ; trois écarts
seulement, notés au §« Chaîne d'outils » ci-dessous.

### Chaîne d'outils reconstituée

| Élément | Version | Emplacement | Écart avec la procédure |
|---|---|---|---|
| Python | 3.12.10 | `%LOCALAPPDATA%\Programs\Python\Python312` | — |
| PlatformIO Core | 6.1.19 | `Python312\Scripts` | **et non `~\.platformio\penv\Scripts`** : le §3.2 décrit l'installeur `get-platformio.py`, ici c'est `pip` |
| Jonction `C:\esp-clim` | — | → `C:\Users\rigon\Documents\Esp Controle clim` | — |
| ESP-IDF | v5.4 et v6.0.1 | `C:\esp\`, outils dans `C:\Espressif` | **déjà présentes**, mais le §7.1 fige **v5.5.3** — sans objet tant que le firmware définitif n'existe pas (§3.6) |

Deux pièges rencontrés :

- `C:\Espressif\tools\python` (3.11, fourni par l'installeur ESP-IDF) répondait à `python`.
  PlatformIO n'y a **pas** été installé, pour ne pas polluer l'environnement de l'IDF. L'installeur
  winget place de lui-même Python 3.12 devant dans le `PATH` utilisateur.
- **Le port n'est plus `COM3` mais `COM4`.** `COM3` existe sur cette machine et désigne un autre
  appareil, un adaptateur CH343. La carte se reconnaît à sa MAC `14:c1:9f:c4:fc:40`, comme prévu au
  §3.5. Toutes les commandes du README §6 ont été corrigées.

Première compilation `pio run -e capture` : **SUCCESS** en 71 s, toolchain Xtensa et
IRremoteESP8266 2.9.0 retéléchargés.

### Cause de la panne du transistor — **une broche, pas un composant**

Le test discriminant prévu (débrancher émetteur → `GND`) n'a pas eu à être joué. La description du
montage a suffi : la résistance de base était reliée à **`D2`**, alors que `tx_blink.cpp` pilote
**GPIO2, c'est-à-dire `D1`**. La base n'était donc reliée à aucune sortie pilotée — GPIO3 reste en
entrée haute impédance dans ce croquis.

Les trois hypothèses du 1er août étaient toutes fausses, et pour la même raison : elles cherchaient
la panne dans le chemin du courant de collecteur, alors qu'elle était dans la commande.

Aucun des symptômes n'était donc à interpréter — le transistor était sain depuis le début, comme le
TSOP l'avait été avant lui. **Le fil déplacé de `D2` vers `D1` a suffi.** Phases 1 et 2 conformes,
clignotement observé.

Le brochage du §6.0 est conservé sans discussion : `D2`/GPIO3 est réservé à la **réception** pour le
montage définitif du §6.2, y mettre l'émission créerait un conflit ultérieur.

### Outil créé — boucle locale émission → réception

`ir-capture/src/tx_loopback.cpp`, environnement `loopback`. **Seul croquis où les deux étages sont
montés en même temps.** Il émet une trame `TOSHIBA_AC` de 72 bits sur `D1`, la fait redécoder par le
TSOP, et compare les neuf octets envoyés à ceux reçus.

Trois trames d'essai : celle réellement mesurée le 1er août (21 °C), et deux dérivées à 17 et 30 °C
dont le checksum est recalculé au démarrage par la formule du §8.3. Les dérivées ne prouvent rien sur
le protocole — elles ne servent qu'à éprouver les timings sur des motifs de bits différents.

Ce que la boucle prouve : porteuse 38 kHz présente, durées correctes, chaîne GPIO → transistor → LED
sans déformation. Ce qu'elle ne prouve pas : que la clim obéit. La preuve n° 2 du §2.3 exige l'unité
intérieure.

### Fausse piste — le récepteur, une fois de plus

Premier passage de la boucle : **zéro trame reçue**, et surtout **zéro front** sur la sortie du TSOP.
Écarter la LED du récepteur puis le réorienter n'a rien changé : toujours zéro. Une saturation par
proximité produirait des trames déformées, pas un silence total — l'hypothèse a été écartée sur ce
raisonnement.

Un troisième croquis a servi à descendre d'un cran : `ir-capture/src/tx_carrier.cpp`, environnement
`carrier`. Il sépare quatre régimes — éteint, continu, porteuse 38 kHz permanente, salves de
600/600 µs — et compte les fronts vus par le TSOP dans chacun. La porteuse y est produite par le
**PWM matériel (LEDC)** et non par la boucle logicielle de la bibliothèque, ce qui retire le logiciel
de l'équation.

Le verdict est tombé pendant l'exécution, entre deux cycles, au moment où l'inversion `OUT`/`VS` du
TSOP était corrigée :

```text
                        cycle 1        cycle 2
salves 600/600 µs       0 front        4868 fronts
porteuse continue       0 front          76 fronts
```

**L'étage d'émission n'a jamais été en cause.** Il tient les 38 kHz sans réserve, même à 15 mA.

### Le contrôle statique de câblage est trompeur — à ne plus utiliser seul

Le `checkWiring()` de `main.cpp`, repris dans la boucle, s'est trompé **dans les deux sens au cours de
la même session** :

| Câblage réel | Verdict de `checkWiring()` | Réception effective |
|---|---|---|
| `OUT`/`VS` inversés | `20/20 HAUT` → « OK » | **aucune** |
| correct | `0/20 HAUT` → « ÉCHEC » | **parfaite, 12 trames sur 12** |

Le test met la broche en entrée avec tirage vers le bas et conclut d'un niveau haut que le TSOP tient
la ligne. Mais la sortie du TSOP est à collecteur ouvert avec un tirage interne d'environ 30 kΩ, face
à un tirage vers le bas interne de l'ESP32 du même ordre : le pont diviseur tombe **sous le seuil
d'entrée haut**. Un niveau lu bas ne dit donc rien de l'état du récepteur.

Cela invalide la conclusion posée le 1er août plus haut dans ce journal — « un niveau bas permanent
signifie donc "pas d'alimentation", jamais "pas de signal" ». Elle n'est vraie que lorsque la broche
lue est tenue par une source basse impédance, ce qui était le cas par accident quand `OUT` et `VS`
étaient inversés.

**Le seul indicateur fiable est le comptage de fronts pendant une émission connue**, tel que
`probeActivity()` l'implémente dans `tx_loopback.cpp`. Il distingue « ne voit rien » de « voit mais ne
décode pas », ce qu'aucune mesure statique ne peut faire.

`main.cpp` n'a **pas** été modifié : c'est l'instrument validé de la campagne du §8.2 et ses relevés
sont irremplaçables. Son `checkWiring()` reste donc à lire comme indicatif, jamais comme un verdict.

### Résultat — boucle locale **SUCCÈS, 12 trames sur 12**

```text
Fronts detectes pendant l'emission : 296

Emission : mesuree 21 C
  envoye  : F2 0D 03 FC 01 40 00 00 41
  protocole : TOSHIBA_AC, 72 bits
  recu    : F2 0D 03 FC 01 40 00 00 41
  OK : les neuf octets reviennent identiques.

Cumul : 12 reussites, 0 echecs
```

Quatre passes consécutives, les trois trames à chaque fois, **aucun écart d'un seul octet**. Le
décodeur reconnaît `TOSHIBA_AC` 72 bits sur notre propre émission, au même titre que sur la
télécommande d'origine.

**Sortie de phase 1b atteinte.**

### Jalon de passage du §2.3 — état

1. **Cinq captures cohérentes d'une même commande** — partiel. Quatre relevés validés dans
   `captures/raw/`, il en faut cinq par commande sur toute la matrice du §8.2.
2. **Retransmission brute commandant réellement la clim** — **toujours non acquise.** Ce n'est plus
   un problème d'électronique mais de lieu : la mesure exige d'être devant l'unité intérieure
   (migration-nouveau-pc.md §6).
3. **Identification reproductible du préambule, de la longueur et du checksum** — fait le 1er août.

**Suite, dans l'ordre :**

- Preuve n° 2, devant la clim, avec `loopback` ou une variante n'émettant que `off` et
  `cool_22_auto_off` — c'est ce que recommande la stratégie de repli du §8.4.
- Puis la campagne du §8.2. Attention : `captures/README.md` impose de **démonter l'étage
  d'émission** pendant cette phase, il pollue les relevés. Les deux étapes ne peuvent pas être
  menées de front.
- Le codec ne s'écrit qu'après, faute de quoi les champs mode, ventilation et swing seraient
  supposés plutôt que mesurés.

---

## 1er août 2026 — Interface Web, écrite avant le firmware

La clim est momentanément inaccessible. C'est précisément le travail que cela n'empêche pas :
la décision « interface servie en fichiers statiques » (cahier v2 §4.2) rend `web/` indépendant du
codec, du réseau et de la carte. L'interface a donc été écrite et mise au point contre une maquette.

### Ce qui a été créé

| Fichier | Rôle |
|---|---|
| `toshiba-climate-controller/web/index.html` | La page : deux cartes, planning, diagnostic, réglages |
| `toshiba-climate-controller/web/app.css` | Style unique, clair et sombre, sans police externe |
| `toshiba-climate-controller/web/app.js` | Toute la logique : interrogation, commandes, éditeur de courbe |
| `toshiba-climate-controller/web/config.example.json` | Adresses des boîtiers, livrées avec les fichiers |
| `tools/mock_api.py` | Maquette d'un boîtier : sert `web/` et l'API, deux instances = deux boîtiers |
| `docs/api-v2.md` | Le contrat que le composant `web_api` devra satisfaire |

Aucune ressource externe, aucune bibliothèque : trois fichiers, **51 ko** en tout, à loger dans une
partition `storage` de 1,875 Mo — 2,7 % de la place disponible. Le graphe à points déplaçables — le seul composant que le cahier v2 §4
identifiait comme « à construire de toute façon » — tient dans un SVG construit à la main.

### Décisions prises en écrivant

**Les capacités viennent du boîtier, jamais de la page.** Modes et vitesses de ventilation sont
lus dans `capabilities`. Le boîtier déclare en plus `unverified_fields` : tant que la campagne du
§8.2 n'a pas mesuré l'encodage de `mode`, `fan` et `swing`, l'interface affiche la pastille **non
vérifié** en face de chacun. C'est la traduction à l'écran de l'état réel des connaissances — la
température, elle, est mesurée, et ne porte pas de pastille.

**La courbe est un escalier.** Un point vaut jusqu'au suivant, le dernier déborde sur le lendemain.
Pas d'interpolation : un thermostat ne rampe pas entre deux consignes, et l'ordonnanceur du firmware
appliquera exactement la même règle de lecture que le tracé.

**Pas de WebSocket.** L'interrogation périodique à 5 s suffit et supprime une dépendance. Conséquence
assumée et notée dans `api-v2.md` : le critère du plan §3.4 — « l'usage de la télécommande met à jour
l'état en moins d'une seconde » — n'est pas tenu par ce choix. Il le sera si `/ws` est ajouté.

**`GET /api/v1/devices` et le champ `role` disparaissent**, conformément au cahier v2 §4.1 : les
boîtiers sont symétriques, l'agrégation se fait dans le navigateur. En contrepartie, l'API doit
porter des en-têtes CORS et accepter un jeton porteur.

### Un mauvais choix corrigé en cours de route

Le graphe était d'abord large de 480 px minimum, dans un conteneur défilant horizontalement. Sur
téléphone, c'était inutilisable : le déplacement des points impose `touch-action: none` sur le SVG,
donc **le seul geste qui aurait pu faire défiler le graphe est celui qui déplace un point.** Les
heures 20 h à 24 h devenaient inatteignables.

Le graphe se met désormais à l'échelle de la carte. Les libellés et les cibles tactiles sont
dimensionnés pour cette réduction : à 375 px de large, l'axe reste à 11 px et une cible de point fait
29 px. La saisie précise, elle, ne passe pas par le doigt mais par l'éditeur de point situé juste en
dessous, où l'heure se règle au champ `time` par pas de 30 minutes.

### Ce qui a été vérifié, dans un navigateur, sur la maquette

| Contrôle | Résultat |
|---|---|
| Deux boîtiers affichés, chacun interrogé à son adresse | OK, requêtes inter-origines comprises |
| Marche/arrêt, température, mode, ventilation, oscillation | OK, `PUT /api/v1/climate` accepté, `revision` incrémentée |
| Ajout d'un point par appui sur la courbe | OK, hérite du réglage courant |
| Déplacement d'un point, 13 h 00 → 19 h 30 à 19 °C | OK, aimantation au pas de 30 min et au degré |
| Point lâché dans la bande basse | OK, devient un point d'arrêt |
| Deux points sur la même demi-heure | Refusé, le point ne se superpose pas |
| Suppression, annulation, enregistrement | OK, `revision` du planning incrémentée |
| Commande concurrente pendant une modification | `409` reçu, état du boîtier adopté, message affiché |
| Boîtier injoignable | Carte grisée et désactivée, l'autre reste commandable |
| Rendu à 375 px | Aucun débordement horizontal, graphe entier visible |

Ce qui n'est **pas** vérifié par ces essais : que les octets envoyés commandent réellement la clim.
La maquette renvoie une trame construite à partir du seul encodage mesuré — préfixe `F2 0D 03 FC 01`,
température dans le quartet haut de l'octet 5, checksum en OU exclusif. Les octets de mode, de
ventilation et de swing y sont à zéro, parce qu'on ne les connaît pas.

### Suite : brancher le TSOP dessus

Le panneau **Diagnostic infrarouge** de chaque carte est fait pour cela. Il affiche côte à côte la
dernière trame émise et celle que le TSOP du même boîtier a relue, avec le verdict de comparaison.
La boucle locale du 1er août prouve déjà que la chaîne émission → réception ne déforme rien : il
reste à l'exposer par HTTP, ce qui donne le contrôle du §14.2 — *vérifier que l'on émet bien ce que
l'on croit* — directement dans l'interface, sans console série.

Cela ne demande ni la clim, ni le codec définitif : un croquis PlatformIO servant `web/` et
réutilisant `IRremoteESP8266` suffirait à valider l'ensemble sur la carte réelle.

---

## 1er août 2026 — L'interface tourne sur la carte, l'émission est contrôlée

Le croquis annoncé ci-dessus a été écrit : `ir-capture/src/webui.cpp`, environnement `webui`. Il sert
`web/` depuis la flash de la carte et implémente les cinq routes de [api-v2.md](api-v2.md). La page
est donc accessible depuis n'importe quel appareil du réseau, téléphone compris.

### Deux points d'organisation

**Le Wi-Fi est dans un fichier à part.** `include/secrets.h`, exclu du dépôt par `.gitignore`
(plan §16.3), avec un modèle versionné `secrets.example.h` qui ne contient rien. Le croquis refuse de
compiler si le fichier manque, avec le message qui dit quoi faire — `#error` plutôt qu'une panne à
l'exécution.

**Il n'y a qu'une copie de l'interface.** `data_dir` de `platformio.ini` pointe sur
`toshiba-climate-controller/web/` : `uploadfs` prend les fichiers à la source. Modifier l'interface
et la redéployer ne touche pas au firmware — c'est exactement la propriété recherchée au cahier v2
§4.2, vérifiée pour de vrai.

### Résultats mesurés sur la carte

| Contrôle | Résultat |
|---|---|
| Compilation | 915 ko, **27,4 %** de la partition applicative de 3,3 Mo |
| Interface en flash | 51 ko écrits à `0x670000`, hash vérifié |
| Connexion Wi-Fi | OK, DHCP `192.168.1.232`, RSSI **−59 dBm** |
| Nom mDNS | `http://clim-salon.local/` répond, sans avoir à connaître l'IP |
| Heure | SNTP synchronisé, fuseau Europe/Paris appliqué |
| Page servie depuis la carte | OK, une seule carte affichée — le second boîtier n'est pas déclaré |
| Commande depuis la page | `PUT /api/v1/climate` accepté, `revision` incrémentée |
| Planning enregistré | OK, `409` correct sur révision obsolète |
| Planning après redémarrage | **conservé** — NVS relu au démarrage |
| `next_point_at` | `23:00` à 20 h 35 un samedi, courbe week-end : correct |
| Ordonnanceur | `[planning] point 08:30 applique` — le point en vigueur est bien celui qui déborde depuis le matin |

### Le contrôle par le TSOP — **il fonctionne**

C'est le point que la maquette ne pouvait pas donner. Consigne portée à 22 puis 23 °C depuis la page :

```text
Derniere emission   F2 0D 03 FC 01 50 01 00 50
Derniere reception  F2 0D 03 FC 01 50 01 00 50   TOSHIBA_AC, 72 bits, propre emission
Checksum            valide
Controle            les octets recus par le TSOP sont identiques a ceux emis
Compteurs           2 emises, 2 valides, 0 rejetees
```

À 23 °C, l'octet 5 passe de `50` à `60` — soit `température − 17` dans le quartet haut, conforme à la
mesure du 1er août. Le checksum suit. **La chaîne page → HTTP → codec → LED → TSOP → décodeur est
donc close, et vérifiable depuis un téléphone sans console série.**

### Ce que ce résultat ne dit pas

L'octet 6 vaut `01` pour le mode froid. Cette valeur ne vient **pas** d'une mesure : elle vient du
modèle *Remote A* d'`IRremoteESP8266`, que le croquis utilise pour construire la trame. La seule
trame réellement mesurée le 1er août était en mode Auto, où cet octet vaut `00` — cohérent, mais un
seul point ne fait pas une preuve.

C'est exactement ce que l'interface annonce en affichant **non vérifié** sur mode, ventilation et
oscillation. La campagne du §8.2 reste donc entièrement à faire, et la preuve n° 2 du §2.3 — la clim
qui obéit — attend toujours d'être devant l'unité intérieure.

### Un piège à noter pour la suite

Ouvrir puis refermer le port série **redémarre la carte** : le DTR de l'USB-Serial-JTAG provoque un
reset, et la ré-énumération USB fait perdre la bannière de démarrage. C'est la manifestation concrète
du §7.1.1 du plan. Conséquence pratique : l'état estimé repart à zéro à chaque ouverture de console —
le planning, lui, est en NVS et survit. Pour connaître l'adresse IP sans console, `clim-salon.local`
ou la page `/healthz` suffisent.

---

## 2 août 2026 — Maintien de l'arrêt contre la télécommande

Besoin exprimé : qu'une plage du planning puisse **maintenir la clim éteinte**, même si quelqu'un
la rallume à la télécommande.

### Ce que l'infrarouge permet, et ce qu'il ne permet pas

L'IR est unidirectionnel et le boîtier n'est pas en série sur le récepteur de l'unité : **il ne peut
pas empêcher la clim de recevoir la télécommande.** Elle démarre. Le seul levier est de renvoyer un
ordre d'arrêt derrière. La fonction s'appelle donc « maintenir éteint » et non « empêcher
l'allumage », et l'interface le dit en toutes lettres à l'endroit où on l'active.

Deuxième limite, du même ordre : le boîtier ne réagit qu'à ce que **son TSOP a vu**. Une télécommande
pointée vers l'unité depuis un angle que le récepteur ne couvre pas passe inaperçue.

### Deux décisions de conception

**Le verrou est un attribut du point de planning**, pas un mode à part : un point d'arrêt peut porter
`"lock": true`, et le segment qui court jusqu'au point suivant maintient l'arrêt. Aucun concept
nouveau — la courbe en escalier portait déjà toute la sémantique nécessaire.

**Le boîtier ne cherche pas à savoir si la télécommande demandait la marche.** C'était la tentation :
décoder la trame reçue, lire le champ mode, n'agir que si ce n'était pas un arrêt. Mais l'encodage du
mode n'est pas prouvé — c'est précisément ce que la campagne du §8.2 doit établir. Bâtir le verrou
dessus, ce serait faire dépendre une fonction de sûreté d'une hypothèse. **Pendant un segment
verrouillé, toute trame reçue vaut donc rappel d'arrêt.** Si elle demandait déjà l'arrêt, le rappel
est sans effet : l'erreur est gratuite dans ce sens-là.

### Le piège évité : l'auto-déclenchement

Le boîtier entend sa propre émission — c'est même ce qui rend l'auto-contrôle possible. Sans
précaution, le rappel d'arrêt aurait été entendu comme une commande de télécommande, aurait déclenché
un nouveau rappel, et ainsi de suite : **une boucle d'émission infinie.** Le RX est donc sourd 1,5 s
après chaque émission — le paquet étant émis deux fois, une fenêtre courte ne suffisait pas. C'est le
masquage de 150 ms du plan §9.2, élargi parce qu'ici on veut aussi couvrir la répétition.

Vérifié sur la carte, et c'est le contrôle qui comptait :

| Contrôle | Résultat |
|---|---|
| Segment verrouillé actif | `lock_active: true`, arrêt appliqué, `source: schedule` |
| **Aucun auto-déclenchement** | après l'émission du planning puis 30 s d'attente : `tx: 1`, **`lock_asserts: 0`** |
| Commande « marche » depuis la page | acceptée, `override_active: true`, `lock_active: false` |
| Retour du verrou après ré-enregistrement du planning | `lock_active: true`, arrêt réappliqué |

La règle de suspension est celle du cahier v2 §3, déjà retenue pour tout le reste : un réglage
manuel tient jusqu'au point suivant. L'interface reste donc maîtresse, la télécommande non — ce qui
est exactement la dissymétrie demandée.

### Ce qui reste à vérifier, et qui demande la télécommande

Le déclenchement réel n'a **pas** pu être testé ici : la seule source infrarouge disponible est la
carte elle-même, et ses émissions sont précisément celles que le masquage ignore. Il faut une trame
extérieure, donc la `WH-TG01NE`.

Le contrôle se lit ensuite dans le compteur `lock_asserts` du diagnostic, ou sur la console :

```text
[telecommande] F2 0D 03 FC 01 50 01 00 50
[verrou] arret renvoye (commande vue a la telecommande)
```

### Outil de secours noté au passage — interface

Le pilote de navigateur s'est bloqué en fin de séance. Edge en mode `--headless=new --dump-dom` a
servi de remplaçant : il exécute réellement le JavaScript et rend le DOM final, ce qui suffit à
vérifier qu'une page se construit — cartes générées, boutons de mode issus des `capabilities`,
pastille de verrou présente. À réutiliser.

---

## 2 août 2026 — « La page est devenue lente » : le réseau, pas le logiciel

Symptôme signalé : l'interface met plusieurs secondes à s'ouvrir, parfois pas du tout.

### Mesures, dans l'ordre où elles ont été prises

```text
temps de reponse (ms)
/healthz             464 / 1380 / 3917 / 2331 / 413
/api/v1/status      9358 / 2907 /  417 / 2080 / 1418
/app.js             7262 / 9910 / 7002            <- 31 ko, soit ~3 ko/s
```

Puis, quelques minutes plus tard, plus rien du tout : huit requêtes de suite en échec, aucun ping,
plus de résolution mDNS — alors que la carte énumérait toujours sur l'USB. **Elle tournait, mais
n'était plus sur le réseau.**

### Instrumentation avant hypothèses

Rien dans le croquis ne permettait de trancher. `/healthz` a donc été étoffé : tas libre, plus gros
bloc allouable, motif du dernier redémarrage, état Wi-Fi, nombre de déconnexions et motif, compteur
de décodages IR **non reconnus** — jusque-là comptés nulle part, ce qui rendait invisible le scénario
« le TSOP voit du bruit en permanence » — et surtout **la cadence de la boucle principale**.

S'y ajoutent deux outils d'essai : `PUT /api/v1/diagnostics/rx` pour débrayer le récepteur à chaud,
et `GET /api/v1/diagnostics/wifi` pour faire balayer la bande par la carte elle-même.

### Ce que l'instrumentation a éliminé

| Hypothèse | Mesure | Verdict |
|---|---|---|
| Fuite ou fragmentation mémoire | 277 ko libres, plus gros bloc 262 ko | **écartée** |
| Processeur accaparé | **24 030 tours de boucle par seconde** | **écartée** |
| Récepteur IR noyé sous le bruit optique | `rx_unknown` = 0 | **écartée** |
| Bande 2,4 GHz encombrée | 3 réseaux en tout, le nôtre seul sur le canal 1 | **écartée** |
| Puissance d'émission réduite | 20 dBm, le maximum | **écartée** |
| Récepteur IR coûteux en temps machine | essai A/B, RX actif puis coupé : 4,7-9,3 s contre 3,8-8,0 s | **écartée**, l'écart est dans le bruit |

### Ce qui reste, et qui est sans appel

```text
             perte   RTT moyen   RTT max
carte ESP32   20 %     480 ms     1510 ms
passerelle     0 %       0 ms        0 ms
```

Le PC est en Ethernet : le trajet PC↔routeur est parfait. **Toute la dégradation est sur le saut
sans fil routeur↔carte.** Un RTT de 480 ms avec 20 % de perte sur un réseau local, bande libre, c'est
une liaison radio en souffrance — un lien sain donne 5 à 30 ms.

**Et la liaison est dissymétrique** : la carte *entend* le routeur à −60 dBm, ce qui est correct,
mais une réponse sur cinq n'arrive pas jusqu'à lui. Elle entend bien, elle est mal entendue.

C'est la signature d'un défaut d'antenne côté carte. Or le plan §5.1 est explicite : *« Le XIAO
ESP32-S3 ne dispose pas d'antenne céramique intégrée : l'antenne externe doit être branchée avant
toute mise sous tension avec le Wi-Fi actif »*, l'inventaire de `migration-nouveau-pc.md` porte
« antenne IPEX — fournie, **pas encore utilisée** », et le §15 liste le risque nommément. Sans
antenne, la carte rayonne par le moignon du connecteur u.FL : assez pour s'associer à quelques
mètres, pas pour tenir un débit.

Le RSSI ne contredit pas ce diagnostic, il ne le voit simplement pas : c'est une mesure de ce que la
carte **reçoit**. Le §14.2 propose de contrôler l'antenne par le RSSI — **cette recette est
insuffisante** et devrait être complétée par une mesure de perte de paquets.

### Trois défauts corrigés au passage — aucun n'est la cause

Ils aggravaient le symptôme sans le créer :

1. **Aucune reprise du Wi-Fi.** `connectWifi()` ne tournait qu'une fois. Une coupure était donc
   définitive jusqu'au redémarrage — exactement ce qui a été observé. Ajout de
   `setAutoReconnect`, d'un gestionnaire d'événements qui journalise le motif de déconnexion, et
   d'une relance explicite après 15 s sans lien. C'est le test §14.4 du plan, qui n'était pas tenu.
2. **Veille radio active.** Réglage par défaut de l'Arduino : la radio s'endort entre deux balises,
   ce qui ajoute des centaines de millisecondes très variables sur un serveur censé répondre à tout
   instant. `WiFi.setSleep(false)`.
3. **Aucun cache sur l'interface.** Le `Cache-Control: no-store` posé pour l'API s'appliquait aussi
   aux fichiers statiques : **53 ko retéléchargés à chaque ouverture de page.** Désormais un ETag,
   empreinte FNV de tous les fichiers calculée au démarrage, et une revalidation qui répond `304`.

   ```text
   app.js, corps complet          14 781 ms
   app.js, revalidation (304)         503 ms
   ```

   Trente fois moins, sur une liaison inchangée. Le `no-store` reste sur l'API, où il a un sens.

### Suite

L'action est matérielle : **brancher l'antenne IPEX, carte hors tension** (§5.1 : le connecteur u.FL
est fragile et la radio ne doit pas démarrer sans antenne). Contrôle attendu après remise sous
tension : la perte de paquets tombe à zéro et le RTT sous 30 ms.

Si l'antenne était déjà en place, les suspects suivants sont, dans l'ordre : connecteur u.FL mal
enclenché ou abîmé — d'où l'antenne de rechange conseillée au §5.1 —, puis les réglages du routeur
Asus BE88U sur la bande 2,4 GHz (802.11ax et WPA3 en mode transition mettent certains ESP32 en
difficulté), puis l'alimentation de la carte.

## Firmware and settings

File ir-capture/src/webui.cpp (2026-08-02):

// ---------------------------------------------------------------------------
// Interface Web sur la carte - banc d'essai avant le firmware ESP-IDF.
//
// Ce croquis sert les fichiers de `toshiba-climate-controller/web/` depuis la
// memoire flash de la carte et implemente les cinq routes de docs/api-v2.md.
// Il rend donc la page accessible depuis un telephone du reseau local, ce que
// la maquette Python (tools/mock_api.py) ne pouvait pas faire.
//
// Ce qu'il apporte en plus de la maquette :
//   - chaque commande de la page EMET une vraie trame TOSHIBA_AC sur la LED IR ;
//   - le TSOP de la meme carte la relit, et la comparaison octet par octet
//     remonte dans le panneau « Diagnostic infrarouge » de l'interface.
//     C'est le controle du plan §14.2 - verifier que l'on emet bien ce que
//     l'on croit - sans console serie.
//
// Ce qu'il n'est PAS : le firmware definitif. Celui-ci sera en ESP-IDF, avec
// OTA, authentification et NVS versionnee (plan §7). Ici, pas de mot de passe :
// a n'utiliser que sur le reseau domestique.
//
// CABLAGE - identique a tx_loopback.cpp, les deux etages montes en meme temps :
//   emission (§6.1)  5V -> 220 ohms -> anode LED IR
//                    cathode LED IR -> collecteur PN2222A
//                    D1 (GPIO2)     -> resistance de base -> base
//                    emetteur       -> GND
//   reception        TSOP VS  -> D3 (GPIO4), sortie a l'etat haut
//                    TSOP GND -> GND
//                    TSOP OUT -> D4 (GPIO5)
//
// Ne pas coller le TSOP a la LED : a moins de 10 cm son AGC sature et la
// trame ressort deformee. Viser 20-50 cm.
//
// PREPARATION
//   1. copier include/secrets.example.h en include/secrets.h et le remplir ;
//   2. televerser les fichiers de l'interface :  pio run -e webui -t uploadfs
//   3. televerser le firmware :                  pio run -e webui -t upload
//   4. lire l'adresse IP sur la console :        pio device monitor
// ---------------------------------------------------------------------------

#include <Arduino.h>
#include <esp_system.h>
#include <WiFi.h>
#include <WebServer.h>
#include <ESPmDNS.h>
#include <LittleFS.h>
#include <Preferences.h>
#include <ArduinoJson.h>
#include <IRrecv.h>
#include <IRutils.h>
#include <ir_Toshiba.h>

#if __has_include("secrets.h")
  #include "secrets.h"
#else
  #error "Copier include/secrets.example.h en include/secrets.h et y mettre le SSID et le mot de passe du Wi-Fi."
#endif

// --- Brochage (plan §6.0, cablage provisoire du README §4) -----------------

const uint16_t kPinTx    = 2;   // D1 - base du transistor
const uint8_t  kPowerPin = 4;   // D3 - alimente VS du TSOP
const uint16_t kRecvPin  = 5;   // D4 - lit OUT du TSOP
const uint8_t  kLedPin   = 21;  // LED de la carte, allumee a l'etat BAS

// --- Reception -------------------------------------------------------------

const uint16_t kCaptureBufferSize = 1024;
const uint8_t  kTimeout           = 50;   // ms, fin de trame
const uint32_t kDecodeWindowMs    = 400;  // attente du retour apres emission

// --- Divers ----------------------------------------------------------------

const char *kFirmware = "0.2.0-webui";
const char *kTimezone = "CET-1CEST,M3.5.0,M10.5.0/3";  // Europe/Paris
const size_t kMaxScheduleBytes = 3500;                 // marge sous la limite NVS
const uint32_t kSchedCheckMs = 5000;                   // cadence d'evaluation du planning

// --- Verrouillage « maintenir eteint » -------------------------------------
//
// L'infrarouge ne permet PAS d'empecher la clim de recevoir la telecommande :
// elle s'allumera. Le boitier ne peut que renvoyer l'ordre d'arret ensuite.
// C'est donc « elle s'eteint aussitot », jamais « elle ne s'allume pas ».

// Delai avant de renvoyer l'arret : laisser l'unite finir de reagir a la
// commande de la telecommande, sinon elle peut ignorer la seconde trame.
const uint32_t kLockReassertDelayMs = 2500;

// Silence minimal entre deux rappels, garde-fou contre l'emballement.
const uint32_t kLockMinIntervalMs = 8000;

// Rappel periodique meme sans rien avoir vu passer. Couvre le cas ou la
// telecommande a ete pointee hors du champ du TSOP. DESACTIVE par defaut (0) :
// la plupart des Toshiba emettent un bip a chaque trame recue, et un bip
// toutes les dix minutes dans une chambre serait pire que le mal.
const uint32_t kLockSweepMs = 0;

IRToshibaAC ac(kPinTx);
IRrecv      irrecv(kRecvPin, kCaptureBufferSize, kTimeout, true);
WebServer   server(80);
Preferences prefs;
decode_results results;

// --- Etat estime (plan §9.1) ----------------------------------------------

struct ClimateState {
  bool     power   = false;
  String   mode    = "cool";
  uint8_t  temp    = 22;
  String   fan     = "auto";
  bool     swing   = false;
  // Vide au demarrage : ce croquis ne conserve pas l'etat en NVS, il n'y a donc
  // rien de « restaure » a annoncer. L'interface n'affiche alors aucune origine.
  String   source  = "";
  String   confidence = "unknown";
  time_t   updated = 0;
  uint32_t revision = 1;
} state;

// --- Planning --------------------------------------------------------------

String   scheduleJson;
bool     overrideActive = false;
int      appliedPointMinutes = -1;   // point de consigne actuellement en vigueur
bool     schedulePrimed = false;     // voir evaluateSchedule()

// --- Verrouillage ----------------------------------------------------------

bool     lockActive = false;         // le segment en cours est marque « lock »
uint32_t rxIgnoreUntil = 0;          // fenetre pendant laquelle le RX est notre echo
uint32_t lockPendingAt = 0;          // date du rappel d'arret a envoyer (0 = aucun)
uint32_t lastLockAssert = 0;
uint32_t counterLockAsserts = 0;

// --- Diagnostic ------------------------------------------------------------

String   lastTxBytes, lastRxBytes, lastRxProtocol, lastRxSource;
time_t   lastTxAt = 0, lastRxAt = 0, lastCheckAt = 0;
uint16_t lastRxBits = 0;
bool     lastRxChecksumOk = false;
int8_t   lastMatch = -1;             // -1 inconnu, 0 ecart, 1 identique
uint32_t counterTx = 0, counterRxValid = 0, counterRxRejected = 0;

// Decodages NON reconnus. Ils n'etaient comptes nulle part, ce qui rendait
// invisible le scenario « le TSOP voit du bruit en permanence » - lumiere du
// jour, halogene, autre telecommande. Or ce bruit coute du temps processeur a
// chaque passage du decodeur (plan §5.3).
uint32_t counterRxUnknown = 0;
bool     rxEnabled = true;   // debrayable a chaud, pour trancher par l'essai

// --- Sante ----------------------------------------------------------------

uint32_t wifiDisconnects = 0, wifiReconnects = 0;
uint8_t  lastDisconnectReason = 0;
uint32_t wifiDownSince = 0;
uint32_t loopCount = 0, loopWindowAt = 0, loopsPerSec = 0;

// ===========================================================================
// Utilitaires
// ===========================================================================

String isoTime(time_t t) {
  if (t < 1600000000) return String();       // heure jamais synchronisee
  struct tm g;
  gmtime_r(&t, &g);
  char buf[24];
  strftime(buf, sizeof(buf), "%Y-%m-%dT%H:%M:%SZ", &g);
  return String(buf);
}

bool timeSynced() { return time(nullptr) > 1600000000; }

String hexBytes(const uint8_t *data, uint16_t len) {
  String out;
  out.reserve(len * 3);
  char buf[4];
  for (uint16_t i = 0; i < len; i++) {
    snprintf(buf, sizeof(buf), "%02X", data[i]);
    if (i) out += ' ';
    out += buf;
  }
  return out;
}

// Traduction vers les constantes de la bibliotheque. ATTENTION : seul
// l'encodage de la temperature est MESURE (journal, 1er aout 2026). Le mode,
// la ventilation et le swing viennent du modele « Remote A » d'IRremoteESP8266
// et restent des hypotheses tant que la campagne du §8.2 n'a pas eu lieu :
// c'est pourquoi l'API les declare dans `unverified_fields`.
uint8_t modeToLib(const String &m) {
  if (m == "cool") return kToshibaAcCool;
  if (m == "heat") return kToshibaAcHeat;
  if (m == "dry")  return kToshibaAcDry;
  return kToshibaAcAuto;
}

uint8_t fanToLib(const String &f) {
  if (f == "low")    return 1;
  if (f == "medium") return 3;
  if (f == "high")   return 5;
  return 0;  // auto
}

// ===========================================================================
// Emission et controle par le TSOP
// ===========================================================================

// Emet l'etat courant, puis ecoute sa propre emission et compare. C'est la
// boucle de tx_loopback.cpp, ramenee a une fonction et exposee par HTTP.
void transmitAndVerify() {
  ac.setPower(state.power);
  ac.setMode(modeToLib(state.mode));
  ac.setTemp(state.temp);
  ac.setFan(fanToLib(state.fan));
  ac.setSwing(state.swing ? kToshibaAcSwingOn : kToshibaAcSwingOff);

  const uint8_t *raw = ac.getRaw();
  const uint16_t len = ac.getStateLength();

  digitalWrite(kLedPin, LOW);          // flash a chaque emission (plan §6.3)

  irrecv.resume();                     // vider ce qui traine avant d'emettre
  ac.send();

  lastTxBytes = hexBytes(raw, len);
  lastTxAt    = time(nullptr);
  counterTx++;

  lastMatch = -1;
  uint32_t start = millis();
  while (rxEnabled && millis() - start < kDecodeWindowMs) {
    if (!irrecv.decode(&results)) {
      delay(1);
      continue;
    }
    if (results.decode_type == decode_type_t::TOSHIBA_AC) {
      lastRxBytes      = hexBytes(results.state, results.bits / 8);
      lastRxBits       = results.bits;
      lastRxProtocol   = "TOSHIBA_AC";
      lastRxSource     = "self";
      lastRxAt         = time(nullptr);
      lastRxChecksumOk = true;         // le decodeur rejette deja un checksum faux
      counterRxValid++;
      lastMatch = (lastRxBytes == lastTxBytes) ? 1 : 0;
    } else {
      counterRxRejected++;
      lastMatch = 0;
    }
    lastCheckAt = time(nullptr);
    break;
  }
  if (rxEnabled && lastMatch < 0) {     // rien recu dans la fenetre
    counterRxRejected++;
    lastCheckAt = time(nullptr);
    lastMatch = 0;
  }

  digitalWrite(kLedPin, HIGH);
  irrecv.resume();

  // Le paquet est emis deux fois : la copie qui traine encore ne doit pas etre
  // prise pour un appui sur la telecommande, sans quoi le verrou se
  // declencherait sur son propre echo, indefiniment (plan §9.2).
  rxIgnoreUntil = millis() + 1500;
}

// ===========================================================================
// Planning
// ===========================================================================

const char *kDefaultSchedule =
  "{\"schema_version\":1,\"enabled\":false,\"timezone\":\"Europe/Paris\","
  "\"revision\":1,\"curves\":{\"week\":[],\"weekend\":[]}}";

void loadSchedule() {
  scheduleJson = prefs.getString("sched", "");
  if (scheduleJson.length() < 10) scheduleJson = kDefaultSchedule;
}

void saveSchedule() { prefs.putString("sched", scheduleJson); }

int minutesOf(const char *hhmm) {
  if (!hhmm || strlen(hhmm) < 4) return -1;
  int h = atoi(hhmm);
  const char *colon = strchr(hhmm, ':');
  int m = colon ? atoi(colon + 1) : 0;
  if (h < 0 || h > 23 || m < 0 || m > 59) return -1;
  return h * 60 + m;
}

const char *activeCurveName() {
  struct tm ti;
  if (!getLocalTime(&ti)) return "week";
  return (ti.tm_wday == 0 || ti.tm_wday == 6) ? "weekend" : "week";
}

// Point en vigueur a `nowMin` : le dernier point dont l'heure est <= nowMin,
// ou, si aucun, le dernier de la journee - la courbe est un escalier qui
// deborde sur le lendemain (api-v2.md §5).
int findCurrentPoint(JsonArray pts, int nowMin) {
  int best = -1, bestMin = -1, lastIdx = -1, lastMin = -1;
  for (size_t i = 0; i < pts.size(); i++) {
    int m = minutesOf(pts[i]["at"] | "");
    if (m < 0) continue;
    if (m > lastMin) { lastMin = m; lastIdx = (int)i; }
    if (m <= nowMin && m > bestMin) { bestMin = m; best = (int)i; }
  }
  return best >= 0 ? best : lastIdx;
}

String nextPointAt() {
  JsonDocument doc;
  if (deserializeJson(doc, scheduleJson)) return String();
  JsonArray pts = doc["curves"][activeCurveName()].as<JsonArray>();
  if (pts.isNull() || pts.size() == 0) return String();

  struct tm ti;
  if (!getLocalTime(&ti)) return String();
  int nowMin = ti.tm_hour * 60 + ti.tm_min;

  int bestMin = -1, firstMin = -1;
  for (JsonObject p : pts) {
    int m = minutesOf(p["at"] | "");
    if (m < 0) continue;
    if (firstMin < 0 || m < firstMin) firstMin = m;
    if (m > nowMin && (bestMin < 0 || m < bestMin)) bestMin = m;
  }
  int target = bestMin >= 0 ? bestMin : firstMin;
  if (target < 0) return String();
  char buf[6];
  snprintf(buf, sizeof(buf), "%02d:%02d", target / 60, target % 60);
  return String(buf);
}

// Applique le planning. Une commande manuelle tient jusqu'au point suivant
// (cahier v2 §3) : c'est le CHANGEMENT de point en vigueur qui reprend la
// main, pas le simple fait qu'un planning soit actif.
void evaluateSchedule() {
  lockActive = false;              // recalcule a chaque passage, jamais suppose
  if (!timeSynced()) return;

  JsonDocument doc;
  if (deserializeJson(doc, scheduleJson)) return;
  if (!(doc["enabled"] | false)) { appliedPointMinutes = -1; return; }

  JsonArray pts = doc["curves"][activeCurveName()].as<JsonArray>();
  if (pts.isNull() || pts.size() == 0) return;

  struct tm ti;
  if (!getLocalTime(&ti)) return;
  int idx = findCurrentPoint(pts, ti.tm_hour * 60 + ti.tm_min);
  if (idx < 0) return;

  // Le verrou appartient au SEGMENT en cours, pas a l'instant de transition :
  // il doit donc etre relu a chaque passage, y compris quand rien ne change.
  lockActive = !(pts[idx]["power"] | true) && (pts[idx]["lock"] | false);

  int at = minutesOf(pts[idx]["at"] | "");
  if (at == appliedPointMinutes) return;
  appliedPointMinutes = at;

  // Au premier passage on note seulement quel point s'applique, sans emettre :
  // un redemarrage ne doit pas envoyer une commande que personne n'a demandee.
  if (!schedulePrimed) { schedulePrimed = true; return; }

  JsonObject p = pts[idx];
  state.power = p["power"] | true;
  if (state.power) {
    state.mode  = String((const char *)(p["mode"] | "auto"));
    state.temp  = (uint8_t)(p["temperature_c"] | 22);
    state.fan   = String((const char *)(p["fan"] | "auto"));
    state.swing = p["swing"] | false;
  }
  state.source     = "schedule";
  state.confidence = "fresh";
  state.updated    = time(nullptr);
  state.revision++;
  overrideActive   = false;

  Serial.printf("[planning] point %02d:%02d applique\n", at / 60, at % 60);
  transmitAndVerify();
}

// Le verrou est-il en vigueur a cet instant ? Une commande passee depuis la
// PAGE le suspend jusqu'au point suivant, comme n'importe quel reglage manuel
// (cahier v2 §3) : l'interface reste maitresse. La telecommande, elle, ne le
// suspend jamais - c'est tout l'objet de la fonction.
bool lockInForce() { return lockActive && !overrideActive; }

void assertLockOff(const char *why) {
  lastLockAssert = millis();
  if (!lastLockAssert) lastLockAssert = 1;
  counterLockAsserts++;
  state.power      = false;
  state.source     = "lock";
  state.confidence = "fresh";
  state.updated    = time(nullptr);
  state.revision++;
  Serial.printf("[verrou] arret renvoye (%s)\n", why);
  transmitAndVerify();
}

// ===========================================================================
// HTTP
// ===========================================================================

void sendCors() {
  server.sendHeader("Access-Control-Allow-Origin", "*");
  server.sendHeader("Access-Control-Allow-Headers", "Content-Type, Authorization");
  server.sendHeader("Access-Control-Allow-Methods", "GET, PUT, POST, OPTIONS");
}

void sendJson(int code, const String &body) {
  sendCors();
  server.sendHeader("Cache-Control", "no-store");   // l'etat, jamais en cache
  server.send(code, "application/json; charset=utf-8", body);
}

void sendError(int code, const char *msg) {
  JsonDocument doc;
  doc["error"] = msg;
  String out;
  serializeJson(doc, out);
  sendJson(code, out);
}

void fillState(JsonObject s) {
  s["power"] = state.power;
  s["mode"] = state.mode;
  s["target_temperature_c"] = state.temp;
  s["fan"] = state.fan;
  s["swing"] = state.swing;
  if (state.source.length()) s["source"] = state.source;
  s["confidence"] = state.confidence;
  String at = isoTime(state.updated);
  if (at.length()) s["updated_at"] = at;
  s["revision"] = state.revision;
}

void handleStatus() {
  // Fraicheur de l'etat (plan §9.2) : quinze minutes.
  if (state.updated && timeSynced()) {
    state.confidence = (time(nullptr) - state.updated < 900) ? "fresh" : "stale";
  } else if (!timeSynced()) {
    state.confidence = "unknown";
  }

  JsonDocument doc;
  doc["schema_version"] = 1;
  doc["device_id"] = CLIM_DEVICE_ID;
  doc["display_name"] = CLIM_DEVICE_NAME;
  doc["online"] = true;
  fillState(doc["state"].to<JsonObject>());

  JsonObject caps = doc["capabilities"].to<JsonObject>();
  caps["temperature_min_c"] = 17;
  caps["temperature_max_c"] = 30;
  JsonArray modes = caps["modes"].to<JsonArray>();
  modes.add("auto"); modes.add("cool"); modes.add("heat"); modes.add("dry");
  JsonArray fans = caps["fans"].to<JsonArray>();
  fans.add("auto"); fans.add("low"); fans.add("medium"); fans.add("high");
  caps["swing"] = true;
  // Tant que la campagne du plan §8.2 n'a pas mesure ces encodages, ils sont
  // annonces comme non prouves : l'interface l'affiche en clair.
  JsonArray unver = caps["unverified_fields"].to<JsonArray>();
  unver.add("mode"); unver.add("fan"); unver.add("swing");

  JsonDocument sched;
  bool schedOk = !deserializeJson(sched, scheduleJson);
  JsonObject so = doc["schedule"].to<JsonObject>();
  so["enabled"] = schedOk ? (bool)(sched["enabled"] | false) : false;
  so["active_curve"] = activeCurveName();
  String np = nextPointAt();
  if (np.length()) so["next_point_at"] = np;
  so["override_active"] = overrideActive;
  so["lock_active"] = lockInForce();
  so["revision"] = schedOk ? (uint32_t)(sched["revision"] | 1) : 1;

  JsonObject tm_ = doc["time"].to<JsonObject>();
  String now = isoTime(time(nullptr));
  if (now.length()) tm_["now"] = now;
  tm_["synced"] = timeSynced();

  JsonObject wifi = doc["wifi"].to<JsonObject>();
  wifi["rssi_dbm"] = WiFi.RSSI();
  wifi["ip"] = WiFi.localIP().toString();

  doc["firmware"] = kFirmware;

  String out;
  serializeJson(doc, out);
  sendJson(200, out);
}
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
void loop() {
  server.handleClient();

  // Cadence de boucle, mesuree sur une fenetre d'une seconde.
  loopCount++;
  if (millis() - loopWindowAt >= 1000) {
    loopsPerSec = loopCount;
    loopCount = 0;
    loopWindowAt = millis();
  }

  // Reprise du Wi-Fi. `setAutoReconnect` suffit dans la plupart des cas, mais
  // pas quand le point d'acces a disparu assez longtemps pour que la pile
  // abandonne : il faut alors relancer la connexion nous-memes.
  if (WiFi.status() != WL_CONNECTED) {
    if (!wifiDownSince) wifiDownSince = millis();
    if (millis() - wifiDownSince > 15000) {
      wifiDownSince = millis();
      wifiReconnects++;
      Serial.println(F("[wifi] plus de connexion, relance"));
      WiFi.disconnect();
      WiFi.begin(WIFI_SSID, WIFI_PASSWORD);
    }
  } else {
    wifiDownSince = 0;
  }

  // Ecoute passive : la telecommande d'origine met a jour l'etat estime
  // (plan §3.1). Ici on se contente de tracer ce qui passe.
  if (rxEnabled && millis() - lastRxPoll > 50) {
    lastRxPoll = millis();
    if (irrecv.decode(&results)) {
      const bool echo = millis() < rxIgnoreUntil;   // reste de notre emission
      if (results.decode_type == decode_type_t::TOSHIBA_AC) {
        lastRxBytes      = hexBytes(results.state, results.bits / 8);
        lastRxBits       = results.bits;
        lastRxProtocol   = "TOSHIBA_AC";
        lastRxSource     = echo ? "self" : "remote";
        lastRxAt         = time(nullptr);
        lastRxChecksumOk = true;
        counterRxValid++;
        if (!echo) {
          Serial.printf("[telecommande] %s\n", lastRxBytes.c_str());
          // On ne cherche PAS a savoir si la telecommande demandait la marche :
          // l'encodage du mode n'est pas encore prouve (campagne §8.2). Pendant
          // un segment verrouille, toute trame recue vaut donc rappel d'arret.
          // Si elle demandait deja l'arret, le rappel est sans effet.
          if (lockInForce() && !lockPendingAt) {
            lockPendingAt = millis() + kLockReassertDelayMs;
          }
        }
      } else if (results.decode_type != decode_type_t::UNKNOWN) {
        counterRxRejected++;
      } else {
        counterRxUnknown++;   // bruit optique : visible dans /healthz
      }
      irrecv.resume();
    }
  }

  if (lockPendingAt && millis() >= lockPendingAt) {
    lockPendingAt = 0;
    if (lockInForce() &&
        (!lastLockAssert || millis() - lastLockAssert >= kLockMinIntervalMs)) {
      assertLockOff("commande vue a la telecommande");
    }
  }

  // Rappel periodique, desactive par defaut : voir kLockSweepMs.
  if (kLockSweepMs && lockInForce() &&
      (!lastLockAssert || millis() - lastLockAssert >= kLockSweepMs)) {
    assertLockOff("rappel periodique");
  }

  if (millis() - lastSchedCheck > kSchedCheckMs) {
    lastSchedCheck = millis();
    evaluateSchedule();
  }
}

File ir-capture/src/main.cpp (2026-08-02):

// ---------------------------------------------------------------------------
// Reconnaissance IR - plan §8.0
//
// Objectif unique : savoir si la telecommande Toshiba WH-TG01NE est reconnue
// par IRremoteESP8266, et sinon recuperer le tableau brut des durees pour la
// matrice de capture du §8.2.
//
// Brochage impose par le plan §6.0 :
//   TSOP38438 OUT -> D2 = GPIO3
//   TSOP38438 VS  -> 3V3 au travers de 100 ohms
//   TSOP38438 GND -> GND
//
// Ce croquis ne fait que recevoir. L'etage d'emission (§6.1) n'est monte
// qu'en phase 1b, une fois des captures exploitables obtenues.
// ---------------------------------------------------------------------------

#include <Arduino.h>
#include <IRrecv.h>
#include <IRac.h>
#include <IRtext.h>
#include <IRutils.h>

// --- Parametres de capture -------------------------------------------------

// Cablage provisoire, valide par l'auto-detection du 1er aout 2026 : le TSOP
// est alimente par une sortie GPIO plutot que par la broche 3V3. Il consomme
// 1,5 mA au maximum, tres loin des 40 mA admissibles par broche. Cela supprime
// la dependance au reperage de la broche 3V3 et aux rangees de la plaque.
//
// Montage definitif (plan §6.2) : VS -> 3V3, OUT -> D2, kPowerPin disparait.
const uint8_t  kPowerPin = 4;  // D3 - alimente VS du TSOP
const uint16_t kRecvPin  = 5;  // D4 - lit OUT du TSOP

// Un climatiseur envoie des trames longues : le tampon doit etre genereux.
const uint16_t kCaptureBufferSize = 1024;

// Fin de trame. Le plan §7.4 retient 20 ms cote RMT ; IRremoteESP8266
// recommande 50 ms pour les protocoles de climatiseur, qui comportent des
// silences internes plus longs que ceux d'une telecommande TV.
const uint8_t kTimeout = 50;

// En dessous de cette taille, un signal "inconnu" est du bruit, pas une trame.
// Abaisse a 6 pendant la mise au point : un signal faible ou partiel doit
// remonter a la console plutot que d'etre filtre en silence. A remonter a 12
// pour la campagne de captures du §8.2.
const uint16_t kMinUnknownSize = 6;

// Seuil du filtre anti-parasite de la bibliotheque, en microsecondes.
const uint8_t kTolerancePercent = kTolerance;  // 25 % par defaut

IRrecv irrecv(kRecvPin, kCaptureBufferSize, kTimeout, true);
decode_results results;

uint32_t frameCount = 0;

// --- Verification de cablage ----------------------------------------------
//
// La sortie du TSOP38438 est a collecteur ouvert avec tirage interne : au
// repos elle est tiree au niveau HAUT. En activant un tirage vers le bas
// cote ESP32, on distingue trois cas :
//   - lecture HAUT  -> le TSOP est alimente et pilote la ligne : cablage OK
//   - lecture BAS   -> rien de connecte, ou TSOP non alimente, ou OUT/GND
//                      inverses, ou saturation lumineuse permanente
void checkWiring() {
  pinMode(kRecvPin, INPUT_PULLDOWN);
  delay(50);

  // Plusieurs lectures : un TSOP sature par la lumiere peut osciller.
  uint8_t highCount = 0;
  for (uint8_t i = 0; i < 20; i++) {
    if (digitalRead(kRecvPin) == HIGH) highCount++;
    delay(5);
  }

  Serial.println(F("--- Verification du cablage (plan §1a) ---"));
  Serial.printf("GPIO%d au repos : %d lectures HAUT sur 20\n", kRecvPin, highCount);

  if (highCount >= 19) {
    Serial.println(F("OK : le TSOP38438 est alimente et tient la ligne au niveau haut."));
  } else if (highCount == 0) {
    Serial.println(F("ECHEC : ligne au niveau bas en permanence."));
    Serial.println(F("  Verifier : alimentation 3V3 du TSOP, resistance 100 ohms,"));
    Serial.println(F("  brochage 1=OUT 2=GND 3=VS dome vers soi, et la liaison OUT -> D2."));
  } else {
    Serial.println(F("SUSPECT : la ligne bascule au repos."));
    Serial.println(F("  Cause probable : saturation lumineuse (soleil, halogene, LED a"));
    Serial.println(F("  decoupage) ou decouplage absent (100 nF + 4,7 uF, plan §6.2)."));
  }
  Serial.println();
}

void setup() {
  Serial.begin(115200);

  // L'USB-Serial-JTAG reenumere a chaque reset : laisser le temps a l'hote.
  uint32_t start = millis();
  while (!Serial && millis() - start < 3000) delay(10);
  delay(500);

  Serial.println();
  Serial.println(F("==========================================================="));
  Serial.println(F(" Reconnaissance IR - Toshiba WH-TG01NE - plan §8.0"));
  Serial.printf(" IRremoteESP8266 v%s\n", _IRREMOTEESP8266_VERSION_STR);
  Serial.printf(" Reception sur GPIO%d (D4), alimentation par GPIO%d (D3)\n",
                kRecvPin, kPowerPin);
  Serial.printf(" Tampon %d symboles, fin de trame %d ms\n",
                kCaptureBufferSize, kTimeout);
  Serial.println(F("==========================================================="));
  Serial.println();

  // Alimente le TSOP et laisse son etage d'entree se stabiliser.
  pinMode(kPowerPin, OUTPUT);
  digitalWrite(kPowerPin, HIGH);
  delay(150);

  checkWiring();

  irrecv.setUnknownThreshold(kMinUnknownSize);
  irrecv.setTolerance(kTolerancePercent);
  irrecv.enableIRIn();

  Serial.println(F("Pret. Pointer la telecommande vers le TSOP a 20-50 cm"));
  Serial.println(F("et appuyer sur une touche (plan §8.2)."));
  Serial.println();
}
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

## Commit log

2026-08-02 Import initial du projet : outils de capture IR, interface Web et documentation
    Pilotage infrarouge de climatiseurs Toshiba par ESP32-S3.
    - ir-capture/ : sept croquis PlatformIO (capture, scan, autodetect,
    txtest, carrier, loopback, webui) pour la mise au point IR
    - captures/ : releves valides de la telecommande WH-TG01NE, checksum verifie
    - toshiba-climate-controller/web/ : interface Web servie en fichiers statiques
    - tools/ : export des journaux de console en JSON, maquette d'API sans materiel
    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
2026-09-03 README : présentation avec photos, carnet de mise au point déplacé dans docs/
    [boitier-clim.step]
